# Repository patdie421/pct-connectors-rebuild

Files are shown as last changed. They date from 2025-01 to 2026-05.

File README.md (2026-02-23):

# pct-connectors-rebuild
This repository consolidate all the elements which allow to use an "AE PC Transporter" card in an Apple IIe (my first usage), II+ or IIgs. In particular, It contains elements allowing to recreate the cables and connectors which are generally lost when one of these cards is found.  
Most of the data used to produce the resources of this repository comes from various sources available on the Internet and are referenced in the “useful links” section.  
Colorswitch PCB was created by retro-ingeniring and original card.

<div style="text-align:center;">

figure 1: PC Transporter rev D  
<p>figure 1: PC Transporter rev D (front view)</p>
</div>

## Connector locations  
### PCT Card
<div style="text-align:center;">

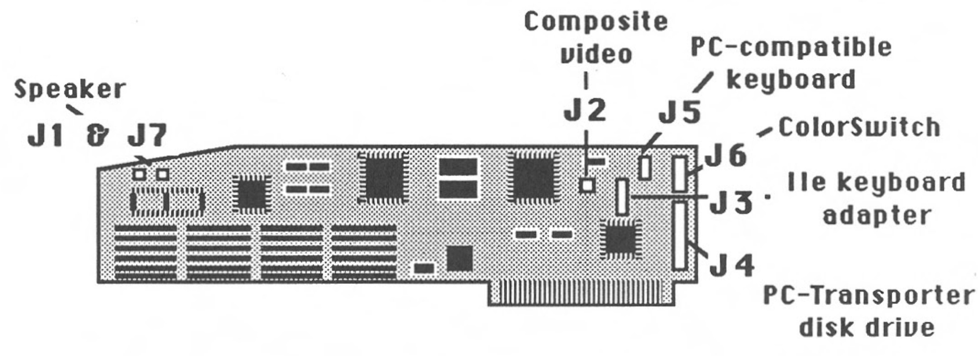
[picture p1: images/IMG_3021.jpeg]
figure 2: PC Transport connector location

<p style="text-align:center;">figure 2: front view card diagram with connector locations</p>
<pre>
J1 - Apple II Speaker motherboard connector (INPUT)
J2 - Composite video (OUTPUT)
J3 - IIe keyboard adapter (INPUT)
J4 - PC Transporter Disk drive (INPUT/OUTPUT)
J5 - PC Compatible keyboard (XT protocol) (INPUT)
J6 - ColorSwitch/CGA (OUTPUT)
J7 - Apple II Speaker (OUTPUT)
</pre>
</div>

### Apple IIe
<div style="text-align:center;">

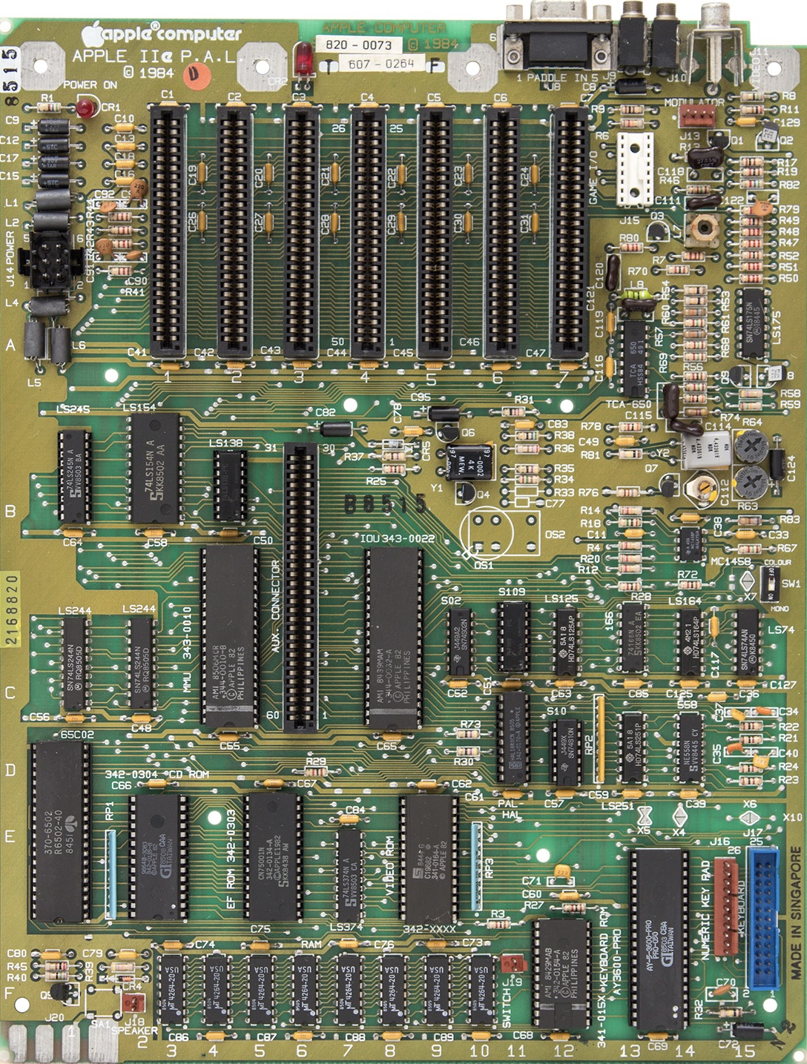
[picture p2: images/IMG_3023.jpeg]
figure 3: Apple IIe PAL motherboard
  
<p>figure 3: Apple IIe PAL motherboard</p>

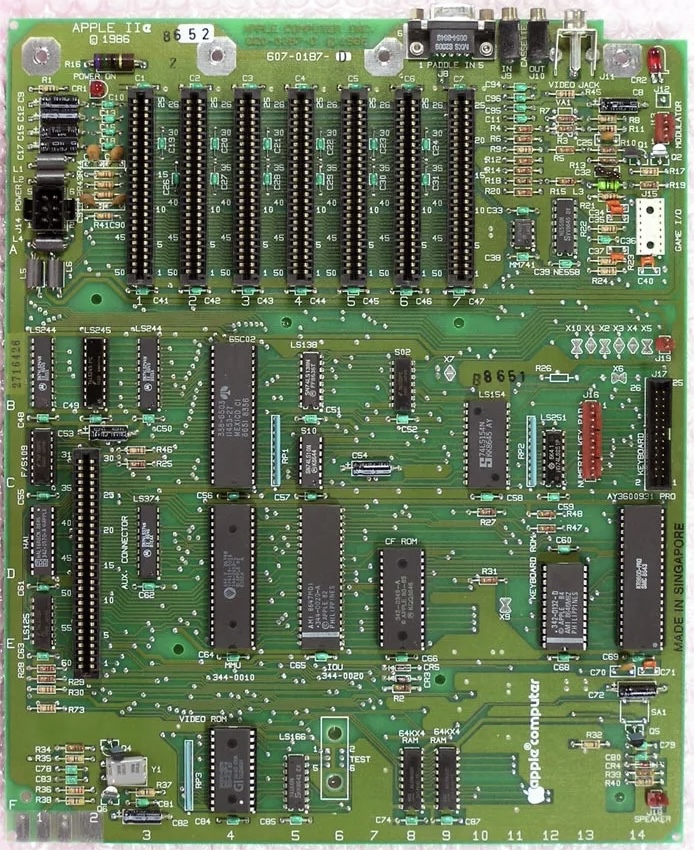
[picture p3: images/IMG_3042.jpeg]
figure 4: Apple IIe (platinum) US motherboard
  
<p>figure 4: Apple IIe (platinum) US motherboard</p>
<pre>
J13 (A14)                  - Composite video (INPUT/OUPUT)
J17 (PAL:E/F15, US:B14)    - IIe keyboard adapter (INPUT)
PAL:J18 (F2), US:J10 (F14) - Apple II Speaker motherboard connector (OUTPUT)
</pre>
Note the different spacing between the keyboard connector (J17) and the numeric keypad connector (J16) of the two card versions.  
</div>

### Original PCT Installation Kit contents
AE solded 2 installation kits to use the card with Apple II+, IIe or Apple IIgs.  

#### IIgs installation kit
- Colorswitch  
- Drive cable  
#### II+/IIe installation kit
- Drive cable  
- Keyboard cable(*)  
- video cable  
- speaker cable  

(*) Apple II+, need an aditional cable for connecting a PC/XT keyboard (kit keyboard cable is inusable for II+) : IBM Keyboard Cable.  
  
#### Digital RGB Adapter (CGA monitor cable)
On II+, IIe and GS you can use a second monitor to display PCT video output. A optional cable was solded by AE.  

## Video Composite output (video cable)
Simple two wires cable. Cheap female/female jumper wire can be used.  
PCT Card outputs an monochrome NTSC composite video signal on J2. PAL motherboards can nevertheless be wired to this Molex connector, but the monitor must be able to switch NTSC and PAL signals (Apple Monitor II is OK for that but the image will "move" a little vertically).  
### PCT Molex connector
<pre>
____
|2||   Video Composite (NTSC)
|1||   GND
----
(PCT connector front view)
</pre>
### Apple II internal Video Connector (J13)
<pre>
===========
| 4 3 2 1 |
-----------
(Apple 2 connector front view)

1  GND
2  Video Composite (NTSC or PAL)
3  -5V
4  +12V
</pre>

### Video Cable
<pre>
Molex  Apple II connector
1  -   1
2  -   2
   -   3
   -   4
</pre>

### status
done, working.

## CGA Video cable (AE: Digital RGB Adapter)
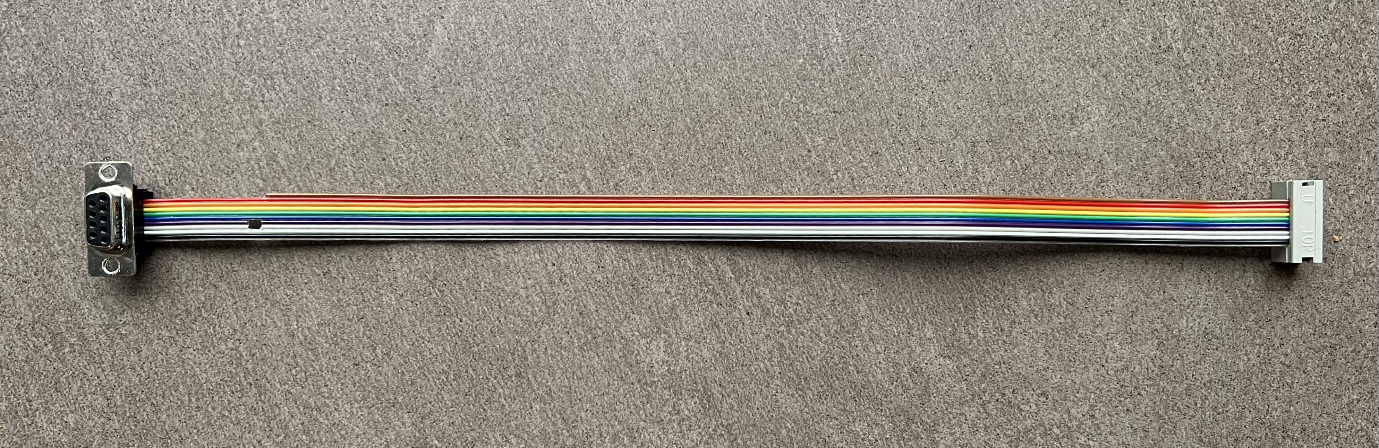
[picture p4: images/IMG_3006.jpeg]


This cable is to use to output video signal directly to a CGA compatible monitor (TTL monitor). Apple II and PCT card can't share easily the same connection for this kind of video connection. Same monitor can display Apple II and PCT signal but for now through two different cables and adaptors (some monitor can automatically switch inputs and "emulate" composite switch or colorswitch behavior)

One side is a DB9 Male connector.
Other one a "10 pins male IDC connector".

Ribbon cable mount connectors are the best way to make this cable. Some parts that could be used :

- IDC : https://fr.farnell.com/en-FR/wurth-elektronik/61201025821/plug-idc-2-54mm-strain-relief/dp/2356318
- DB9 : https://fr.farnell.com/en-FR/multicomp-pro/8ftm09p-30n1-fec/plug-idc-d-threaded-9way/dp/1099306

### 10 pin IDC Male  
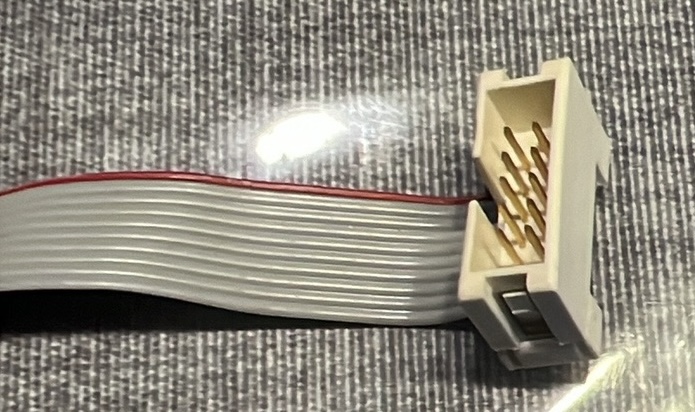
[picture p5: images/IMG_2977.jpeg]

<pre>
(cabel connector front view)  
____________________   
| 2   4   6   8  10|  
| 1   3   5   7   9|  
--------|   |-------  
  |1             |  
  |ribbon  cables|  
  
1 GND
2 Intensity
3 NC for CGA - Source selection for Colorswitch (PCT output signal on CGA/Composite)
4 NC for CGA - CSync for Colorswitch
5 Red
6 HS for CGA - NC for Colorswitch
7 Green
8 VS for CGA - NC for Colorswitch
9 Bleu
10 -
</pre>

### DB9 Female
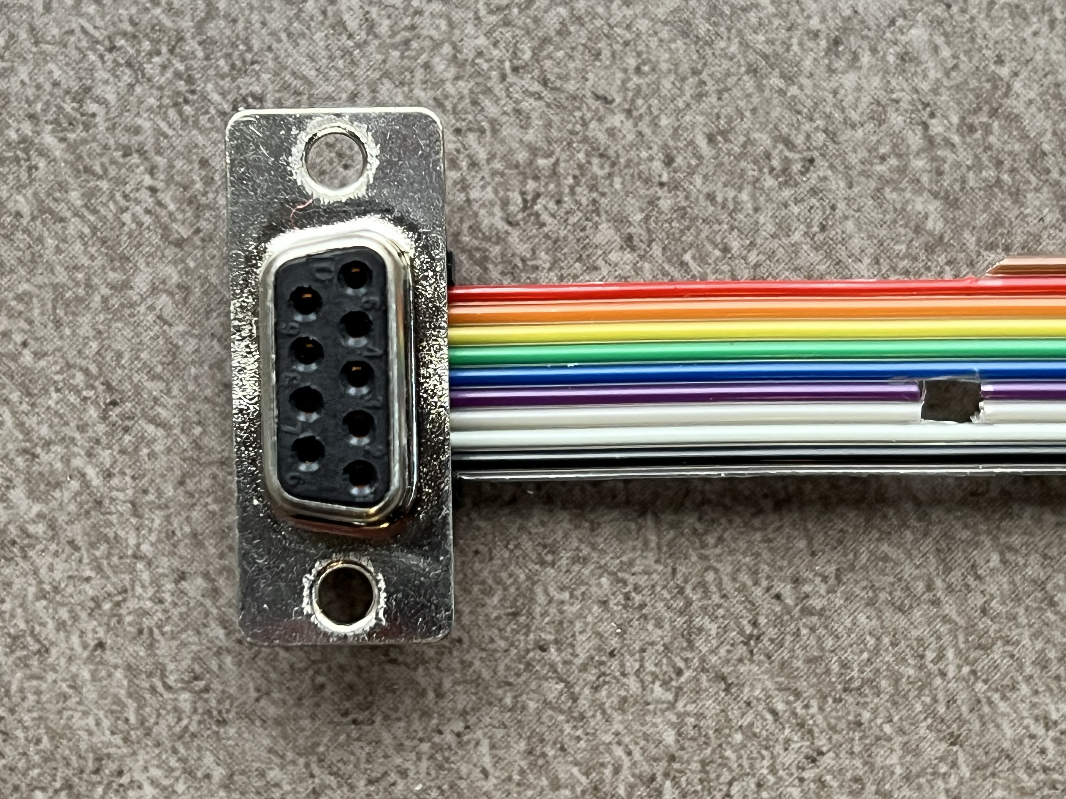
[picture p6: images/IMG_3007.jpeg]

(note the cutout in the ribbon cable)  
  
<pre>
 | ribbon  |
 | cables  |
_|_______ 1|_
\ 5 4 3 2 1 /
 \ 9 8 7 6 /
  ---------
(cable connector front view)

Pin  CGA Function
1    GND
2    GND
3    Red
4    Green
5    Blue
6    Intensity
7    Reserved
8    Horizontal Sync
9    Vertical Sync
</pre>

### Cable
<pre>
IDC      DB9  
  1  --  1  
  2  --  6  
  3  xx  2  
  4  xx  7  
  5  --  3  
  6  --  8  
  7  --  4  
  8  --  9  
  9  --  5  
  10  
</pre>
Do not connect 3 and 4 IDC pins. Cut strands 3 and 4 of the ribbon cable (see photo).  
### usage
The cable connects to J6. There is no key on the male connector, the cable "points" to the right (female connector notch on the right if you look at the board as it is shown in Figure 1). 
### Bonus
You can have cristal clear output on HDMI monitor by using RGBtoHDMI (https://github.com/hoglet67/RGBtoHDMI). The profile to use is : [Commodore/Commodore 128 CGA Brown]  
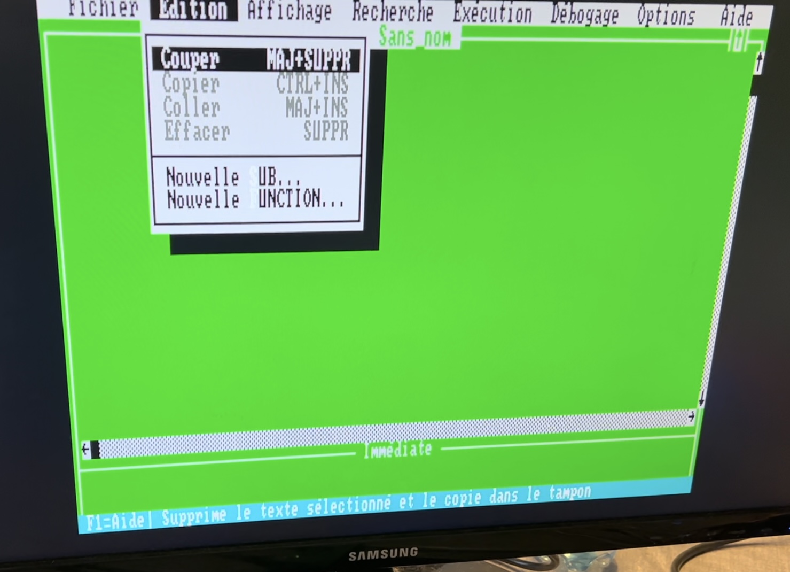
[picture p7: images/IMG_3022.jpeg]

### status
done, working.

## AE ColorSwitch
The ColorSwitch was designed to allow a PCT-equipped Apple IIGS to display CGA on a standard A2M6014 monitor or a compatible RGB monitor (ex: Sony RGB Monitor, cf AE catalog). When the PCT software is running, the display automatically switches Apple screen to CGA screen.  
This card can also be used with an Apple 2e using an RGB color card (Chat Mauve Féline in my case).  
<div>
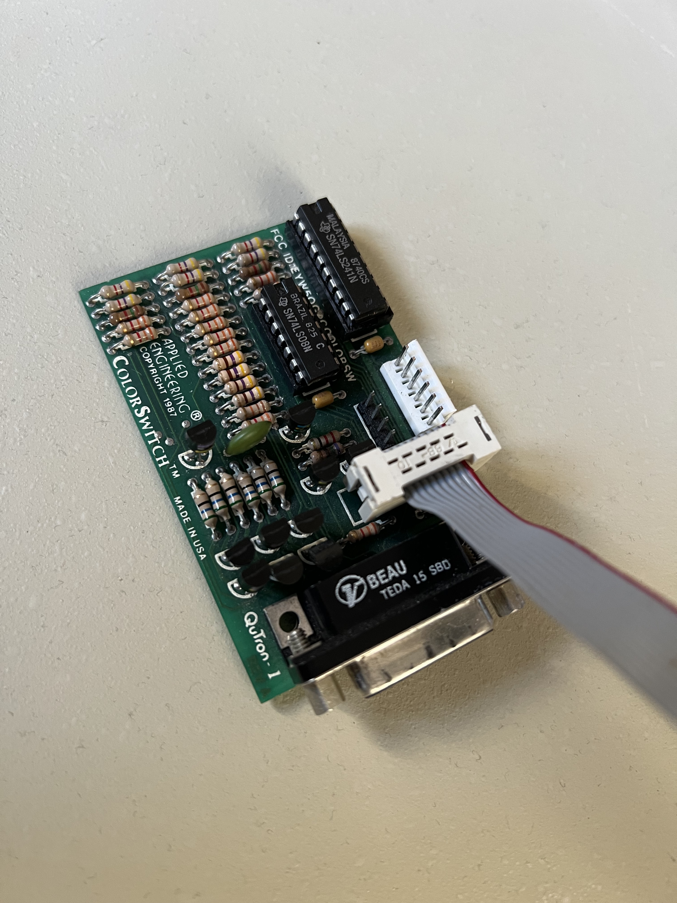
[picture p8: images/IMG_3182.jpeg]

</div>
<div>
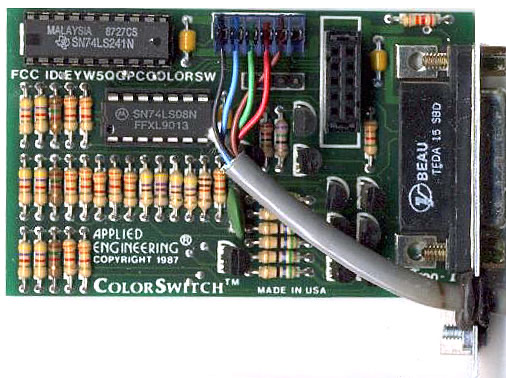
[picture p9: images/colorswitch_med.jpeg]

</div>

### PCB
A design is available in "hardware" folder (v0.0 is buggy, v0.2 should work).  
This design differs from the original device. The implementation density of components is reduced (easier to solder) and the faulty and unused/useless* composite video signal circuit has been removed.  
(*) would have been useful with a specific monitor able to display RGB and composite. Could be add in a futur version.   
<div>
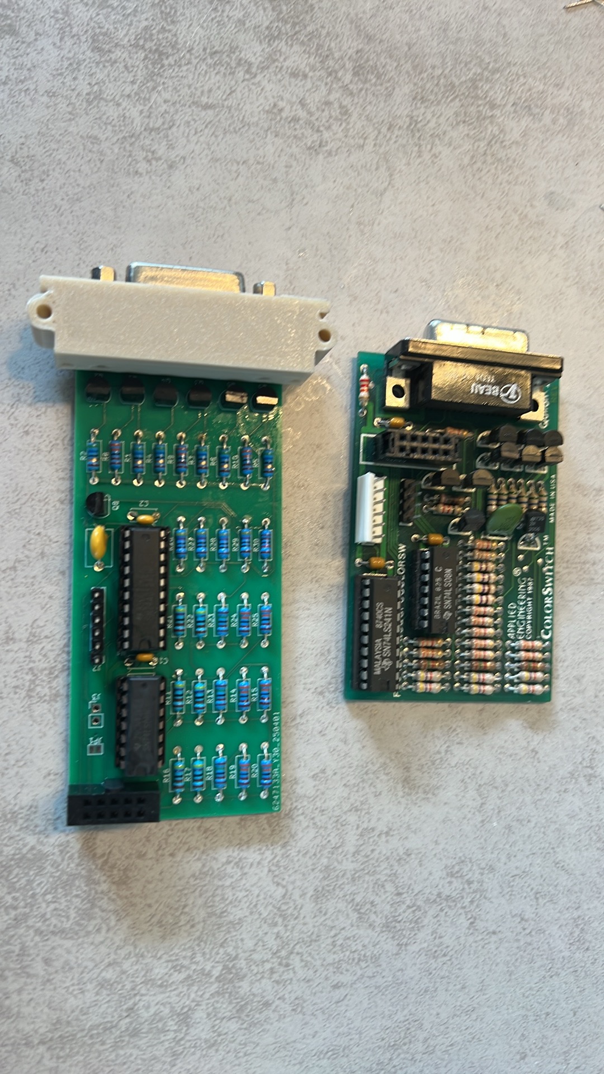
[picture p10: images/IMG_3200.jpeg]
   
   Rebuilt ColorSwitch (v0.0) with DB25 mounting bracket compared to original 
</div>

#### ColorSwitch DB15 female connector
<pre>
1 : RED GND
2 : RED
3 : CSYNC
4 : -
5 : GREEN
6 : GREEN GND
7 : -
8 : -
9 : BLUE
10 : -
11 : -
12 : -
13 : BLUE GND
14 : -
15 : -
</pre>

### ColorSwitch IDC6 connector
<pre>
1 : CSYNC
2 : (composite)
3 : GREEN
4 : RED
5 : BLUE
6 : GND
</pre>

### PCT to Colorswitch cable
flat cable with 2 idc10 male connector.  
<div>
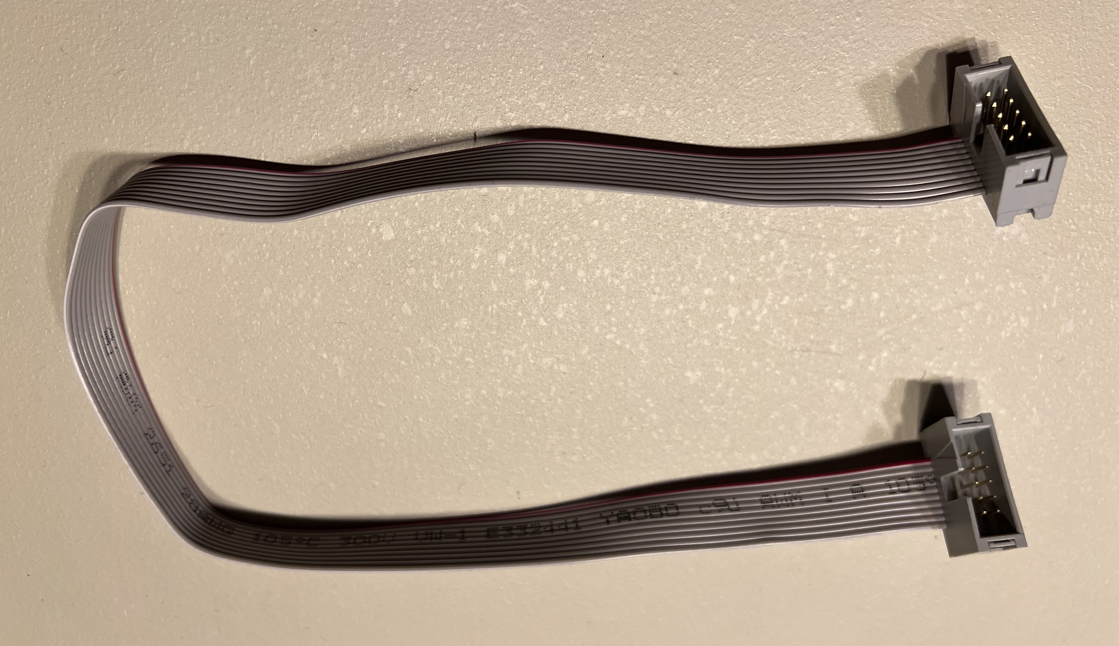
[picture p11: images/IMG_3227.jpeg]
   
</div>
<pre>
IDC10  IDC10  
   1 -- 1
   2 -- 2
   3 -- 3
   4 -- 4
   5 -- 5
   6 -- 6
   7 -- 7
   8 -- 8
   9 -- 9
  10 -- 10
</pre>
flat cable with 2 idc10 male and 1 db9 male connector. To use for double monitor connection.  
(photo)
<pre>
IDC10  IDC10   DB9  
  1  --  1  --  1
  2  --  2  --  6
  3  --  3  xx  2
  4  --  4  xx  7
  5  --  5  --  3
  6  --  6  --  8
  7  --  7  --  4
  8  --  8  --  9
  9  --  9  --  5
  10 -- 10
</pre>

### db15 to Colorswitch (IDC6) cable (for Apple IIGS)
<pre>
DB15 (male)   IDC-6
1 : GND         6
2 : RED         4
3 : CSYNC       1
4 : -
5 : GREEN       5
6 : GND         6
7 : -
8 : -
9 : BLUE        9
10 : -
11 : -
12 : -
13 : GND        6
14 : -
15 : -
</pre>

### Chat Mauve to Colorswitch cable
Several connection are possible. You can use internal (on card) or external connector (throug db connectors).

#### Chat Mauve on card IDC8 connector
<pre>
(card connector front view)  
  =================  
  |1 2 3 4 5 6 7 8|  
  -----------------  
1 - RGB/Composite commutation
2 - Audio out
3 - CSYNC (75 Ohms, 0.5V)
4 - RED (75 Ohms, 0 to 0.7V)
5 - GREEN (75 Ohms, 0 to 0.7V)
6 - BLUE (75 Ohms, 0 to 0.7V)
7 - GND
8 - 12V
</pre>
#### BONUS 1 : Chat Mauve Féline on card IDC10 connector (connector need to be soldered)
<pre>
  (card connector front view)
  ---------------
  |2  4  6  8 10|
  |1  3  5  7  9|
  ---------------  
 1 - NC
 2 - 12v
 3 - GND
 4 - Blue
 5 - Green
 6 - Red
 7 - CSync
 8 - Audio
 9 - NC
10 - NC
</pre>
#### Chat Mauve DB9 female connector
<pre>
 (cable connector front view)
_____________  
\ 5 4 3 2 1 /  
 \ 9 8 7 6 /  
  ---------  
1 : NC  
2 : GND  
3 : GREEN (75 Ohms, 0 to 0.7V)  
4 : CSYNC (negative, 75 Ohms, 0.5V)  
5 : RGB/Composite commutation  
6 : 12V
7 : BLUE (75 Ohms, 0 to 0.7V)  
8 : RED (75 Ohms, 0 to 0.7V)  
9 : Audio out
</pre>

#### BONUS 2 : Chat Mauve to A2M6014 compatible monitor
<pre>
DB9    DB15      IDC8    DB15     IDC10*  DB15
  1 --              1 --             1  --  
  2 -- 1,6,13       2 --             2  --  
  3 -- 5            3 -- 3           3  -- 1,6,13
  4 -- 3            4 -- 2           4  -- 9
  5 --              5 -- 5           5  -- 5
  6 --              6 -- 9           6  -- 2 
  7 -- 9            7 -- 1,6,13      7  -- 3
  8 -- 2            8 --             8  --  
  9 --                               9  --  
                                    10  --  
</pre>

#### BONUS 3 : Colorswitch (or 2gs) to scart cable
##### Scart pinout (wire side view)
<pre>
  _____________________________
 |1  3  5  7  9 11 13 15 17 19 |
 | 2  4  6  8  10 12 14 16 18 20\
  -------------------------------
5  - RGB Ground Blue
7  - RGB Blue In
8  - Switching
9  - RGB Ground Green
11 - RGB Green In
13 - RGB Ground Red
15 - RGB Red In 
16 - Blanking Signal  
17 - Ground Composite Video
18 - Ground Blanking Signal
20 - Composite Video In (CSYNC)
(Only needed pins are listed)
</pre>

##### cable
<pre>
   DB15 (male)     scart (male)
    1,6,13   ---   5,9,13,17,18
      2      ---   15
      3      -*-   20
      4
      5      ---   11
      7
      8      -o-   8
      9      ---   7
     10
     11
     12
     14
     15
(-*-) : direct wire or 190 Ohms resistor
(-o-) optional : to use the cable with the 2gs db15 connector add a 390 Ohms resistor
</pre>

#### BONUS 4 : Chat Mauve TTL / Taxan Model 410-80 connector to rgbtohdmi
It is now possible to use TTL Taxan video card with Colorswitch by using a TTL xRGB to RGB convertor. You can found it a this location: https://github.com/patdie421/xrgb2rgb  

### Status
v0.0 : partially working, color inversion but pcb OK  
v0.2 : done working.  
v0.3 : new smaller PCB - done, working but component mounting issue.  
v0.4 : component position adjustment and sub-d 15 alternative part mount. Tested, working.  

## Storage connector (AE: drive cable)  
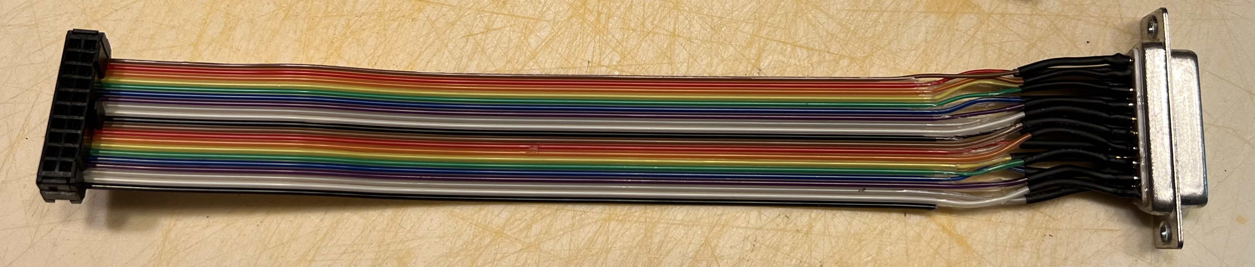
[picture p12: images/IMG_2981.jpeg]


### 20 pin IDC Female  
<pre>
_________________________________________   
| 20  18  16  14  12  10  8   6   4   2 |  
| 19  17  15  13  11   9  7   5   3   1 |  
------------------|   |------------------  
 |                                    1|  
 |           ribbon cables             | 
     (cable connector front view)  
</pre>
### DB19 Female
<pre>
  |                              |
 _|_____________________________1|_
 \  10  9  8  7  6  5  4  3  2  1 /
  \  19 18 17 16 15 14 13 12 11  / 
   ------------------------------  
    (cabpe connector front view)

Pin Function apple pinout
1   GND      GND
2   GND      GND
3            GND
4            GND (IIgs: /3.5DISK bidirectional)
5            -12V
6   5V       +5V
7   12V      +12V
8   12V      +12V
9            /ENABLE2 (IIc /EXTINT)
10           WPROD (Macintosh: PWM)
11           PHASE0
12           PHASE1
13           PHASE2 
14           PHASE3
15           /WREQ
16           (Machintosh: SELECT, IIe/II+: +5V, IIc: N.C., IIgs: SELECT bidirectional)
17           /ENABLE (II+/IIe/IIgs: /ENABLE1)
18           RD
19           WR
</pre>

### Cable
<pre>
IDC    DB9  
1  --  1  
2  -- 11  
3      2  
4     12  
5  --  3  
6  -- 13  
7  --  4  
8  -- 14  
9  --  5  
10 -- 15
11 --  6
12 -- 16
13 --  7
14 -- 17
15 --  8
16 -- 18
17 --  9
18 -- 19
19 -- 10
20
</pre>
### usage
The IDC connector is keyed (the cable is oriented towards the inside of the apple II). Connect 800ko 3.5" Apple floppy drive (/!\ do not connect 3.5" unidisk) or AE Transdrive to DB19 connector. Drive can be daisy chained check documentation.

### status
done, working.

## Apple 2e keyboard adapter (AE: keyboard cable)
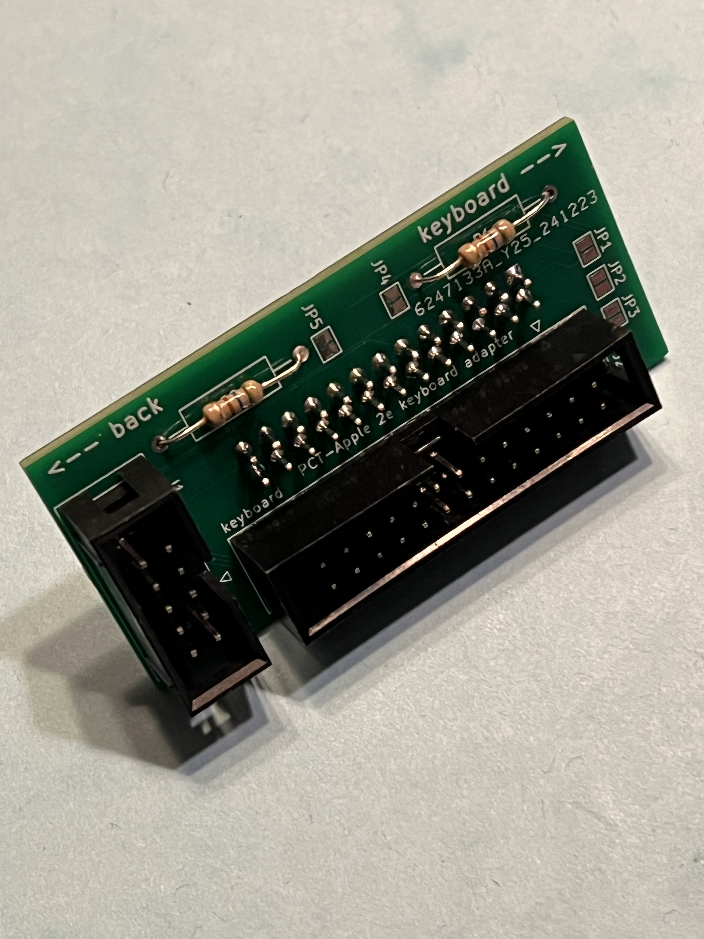
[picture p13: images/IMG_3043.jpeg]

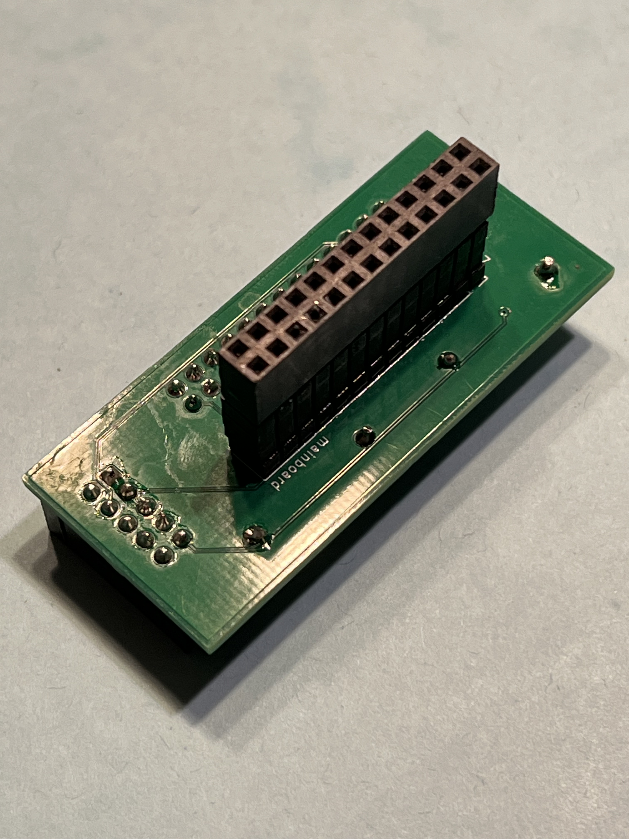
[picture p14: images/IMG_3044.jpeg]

The keyboard adapter is a small PCB and a ribbon cable supplied as an option with the PCT card. This adapter is placed between the Apple motherboard and the keyboard and provides status of "dead keyboard keys" (control, shift, Apple open/close and capslock) to the PCT card. The other signals are only pass-throughs from the keyboard to the motherboard of the Apple 2e.

### connections
Connections are described in this [schema](hardware/a2keyboardToPCT/a2keyboardToPCT.pdf)

### PCB
Based on the connections schema, the PCB can be found in this repository:
[KiCad project and gerber files](hardware/a2keyboardToPCT/V0.0)  
The original version of the connector was designed for a US motherboard. It can be installed on a PAL computer but the connector for the numeric keypad may conflict with the keyboard adapter.  
This PCB is roughly the same size and layout as the original one and therefore may have the same issue. It is best to use elevated female IDC connector if used with PAL Apple IIe (for example https://fr.farnell.com/en-FR/samtec/esq-113-44-t-d/connect-femelle-26-voies-2-rangs/dp/2779437).
### status
done, working.

## PC Compatible keyboard (AE: IBM Keyboard Cable)
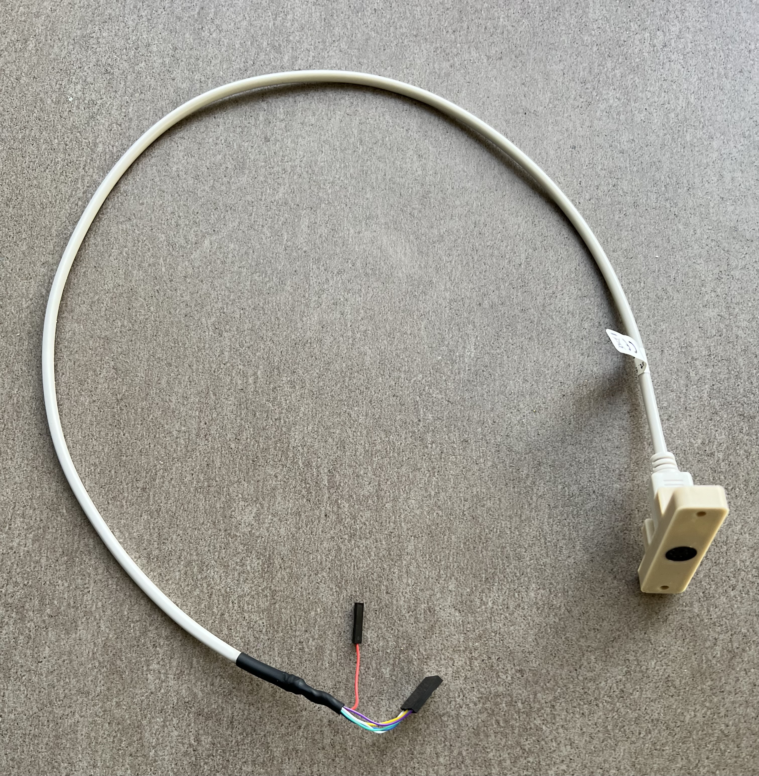
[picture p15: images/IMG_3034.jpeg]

This cable is based on a "PS2 extension cable for keyboard and mouse" (like https://amzn.eu/d/a3pizTv) cut approximately 50 cm after the female connector. An 5 pins JST connector (molex connector alternative) is connected to the cables. The female connector is glued into a 3D printed mounting enclosure that can be attached to one of the db9 or db25 (2 versions available) cutouts on the back of the Apple IIe. This first version of the connector need an AT (PS/2) keyboard able to use the XT protocol. Not all AT keyboards are capable to use this protocol, rare older AT keyboards have automatic or manual switching capabilities from AT to XT protocol.  
<p>
/!\ An active protocol translator for using a ps/2 keyboard as an XT keyboard can be found here: https://github.com/asig/ps2-to-xt-adapter/tree/master. Work is done to integrate it on a small PCB directly pluggable onto the PCT card.
</p>

### Molex connector
<pre>
____
|5||   +5V
|4||   GND
|3||
|2||   Data
|1||   Clock
----
(cable connector frond view)
</pre>

### PS/2 Connector
<pre>
    6  N  5
   4       3
     2   1
(socket/female front view)

Pin   Function
 1    Data
 2    NC
 3    GND
 4    +5V
 5    Clock
 6    NC
</pre>
### PS/2 Cable
<pre>
Molex  PS/2
 1  -  5
 2  -  1
(3  -  2) - 2 unused pins, connection not needed
 4  -  3
 5  -  4
       6
</pre>
### status
Cable: done, working  
XT/AT converter: done, working  
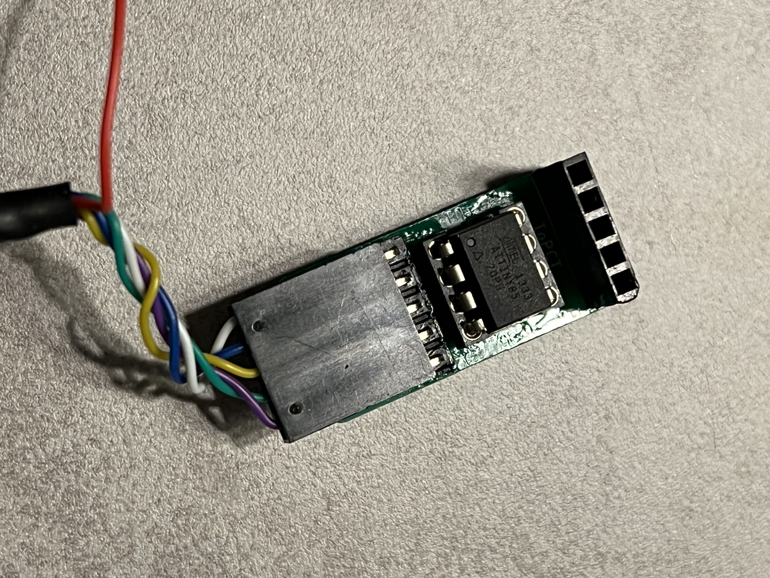
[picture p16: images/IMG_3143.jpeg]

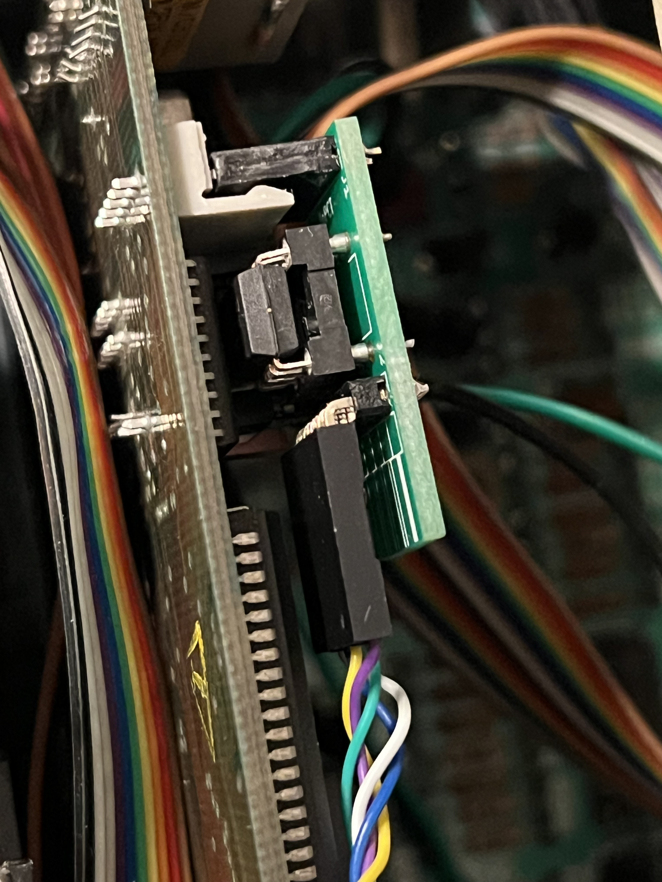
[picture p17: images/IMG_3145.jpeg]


## Sound Connector
One or two Simple two wires (dupont) cable. Cheap female/female jumper wire can be used to connect motherboard J18 to PCT J1. If the speaker cable is long enough it can be connected directly to the J7 connector of the PCT card. If not, a cheap female/male jumper wire can be used.

### PCT Molex connector (J1 / J7)
<pre>
____
|2||   Sound signal
|1||   +5V
----
(PCT connector front view)
</pre>

### Apple II speaker
<pre>
____
|2||   Sound signal
|1||   +5V
----
(Apple II connector front view)
</pre>

## GOTEK + flashfloppy as secondary drive in single TransDrive
3D printed enclosure, configuration and cables.

### Enclosure
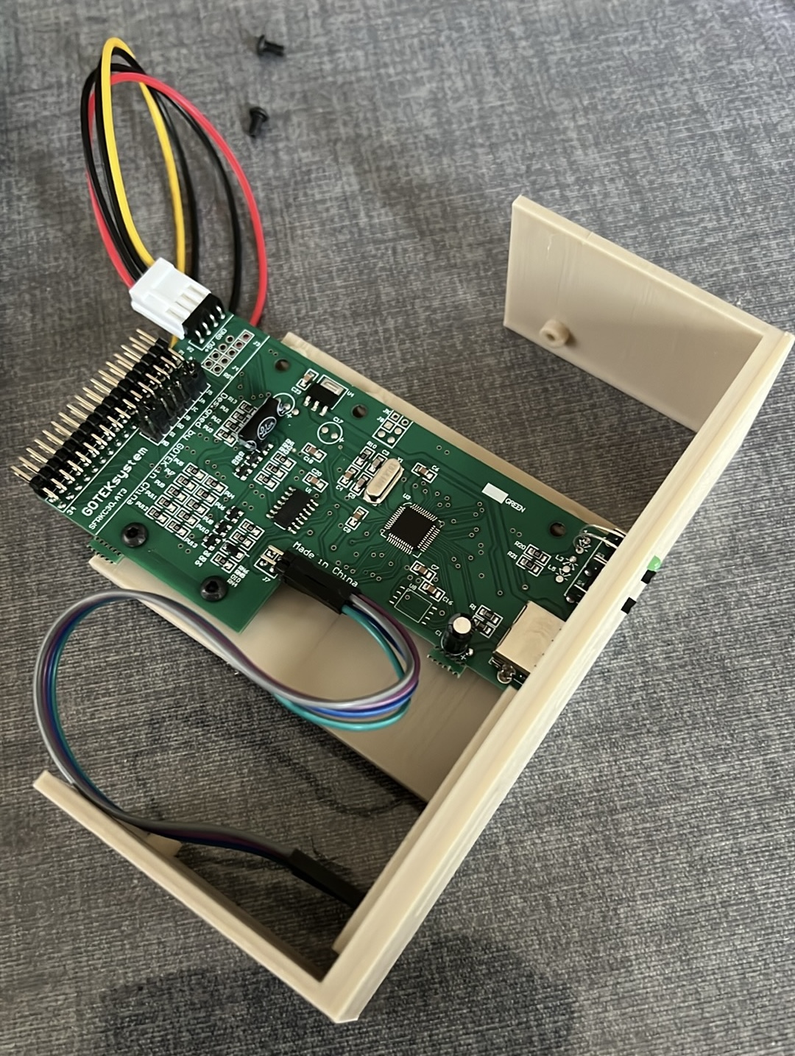
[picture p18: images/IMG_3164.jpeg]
  
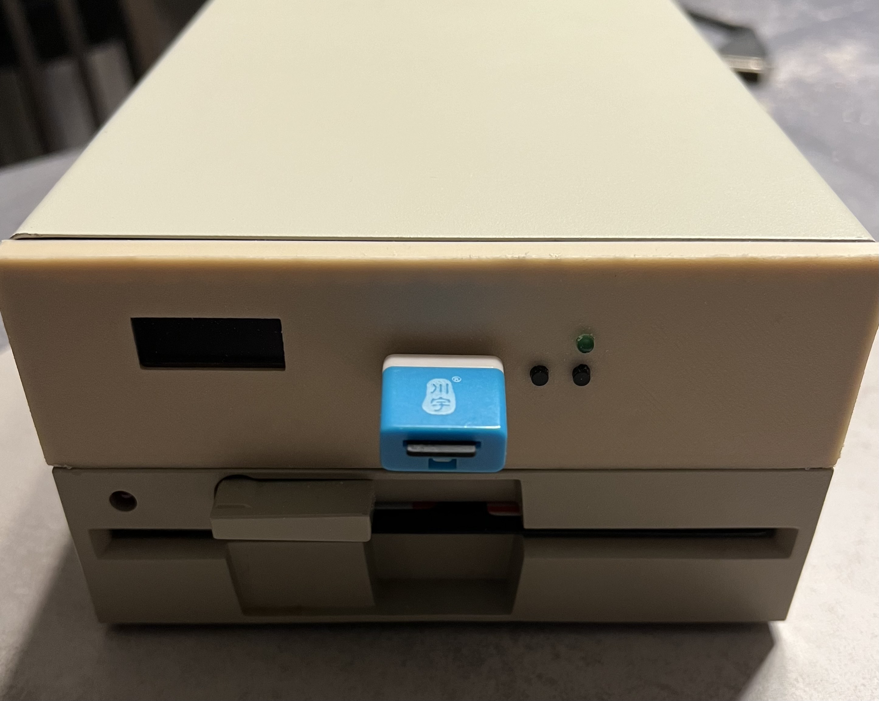
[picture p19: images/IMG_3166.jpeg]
  

[Gotek enclosure with OLED sceen](hardware/transdriveGotek/v0.0)

### Configuration
https://github.com/keirf/flashfloppy  

### Cables
The cable provided with the TransDrive isn't long enough to connect the Gotek. You need to find (or build) an other cable.  
(to do)

## useful links
PCT documentations and software  
https://ae.applearchives.com/all_apple_iis/pc_transporter/  

French PCT documentation  
http://www.apple-iigs.info/doc/fichiers/Brejoux_PC_Transporter%202.pdf  

Various PCT Pinouts and adaptaters (but not exhaustive)  
https://www.applefritter.com/appleii-box/harrowalsh.de/APPLEBOX/APPLE2/Manuals/AE%20PC%20Transporter%20ComponentsPinouts.pdf  

Pinouts, adapters and other resources  
https://osites.tripod.com/transport.html  

Schematics and PCB for 5.25" and 3.5" PC floppy drive adapter rebuild  
https://www.applefritter.com/appleii-box/H070_AppleIITransDriveAdaptor.htm  

Pinouts of various Apple II, Apple IIe, Apple IIc, Apple IIgs and Apple Printers connectors  
https://mirrors.apple2.org.za/ftp.apple.asimov.net/documentation/hardware/misc/Apple%20II%20Family%20Pinouts.pdf  

RGB TTL to RGB Analogic  
https://downloads.reactivemicro.com/Apple%20II%20Items/Hardware/Apple_II_AppleColor_TTI_RGB/TheMarcorlandiModification_TTLRGB.pdf  

Apple 2GS to SCART (for ColorSwitch to SCART)  
https://www.brutaldeluxe.fr/documentation/cortland/v3_03_Schematics.pdf  

For photos  
https://www.applefritter.com/content/applied-engineering-pc-transporter-and-drives

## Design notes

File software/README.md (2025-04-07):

To use the PCT in good conditions it is preferable to have a ProDos hard drive. This disk can be a real disk connected to the II+/IIe/IIgs by one or other of the original solutions (SCSI card + HDD, Apple Profile, etc.) or a modern solution (SmartPort Emulator). However, not all solutions are compatible (I have already identified a solution that did not work), do your own tests if necessary.  

minimum storage device requirements to start MS-DOS with PCT :
- 1x 140ko floppy drive (real or emulated)  
(this solution is to be tested)  

minimal usable configuration :
- 1x ProDOS bootable floppy drive (5.25" floppy drive is OK)
- 1x Apple 3.5" floppy drive (/!\ not Unidisk 3.5") plugged to DB19 connector at the back of the PCT

Optimal solution :
- 1x ProDOS bootable floppy drive (5.25" floppy drive is OK)
- 1x Apple 3.5" floppy drive (/!\ not Unidisk 3.5") plugged to DB19 connector at the back of the PCT
- 1x Real or emulated hard drive (>10 Go)

Top solution :
- 1x ProDOS bootable floppy drive (5.25" floppy drive is OK)
- 1x Transdrive (1x or 2x 5.25") plugged to DB19 connector at the back of the PCT
- 1x Apple 3.5" floppy drive plugged to DB19 connector at the back of the Transdrive
- 1x real or emulated hard drive (On or two 32 Go partitions)

# Prebuild disk images

**pc_transporter_13_disks.zip** (1.32) and **pc_transporter_20_disk.zip** (2.04): original software for PCT Card  

**AEPCHD.2img**: hard drive disk image with PCT software (no dos hdd)  

**PCT204-msdos401us-v0.disk**: Apple II hard drive disk image with PCT 2.04 configured with:  
- A: apple drive 3.5",  
- C: 20MB Hard drive with MS-DOS 4.01 US (full install), no other software installed
- D: PCT Drivers and tools  
(tested with Apple SCSI Card + BlueScsi and LIRON Card + floppy Emu)

**VOL01_HDD01.po**: hard drive disk image with PCT 2.04 configured with:  
- A: transdrive 5.25" (drive 1),
- B: apple drive 3.5" (drive 1),
- C: 30MB Hard drive with MS-DOS 4.01 US (full install) with software :
  - Turbo C++ 1.0
  - Turbo Pascal 5.5
  - Wordstar 4
  - Norton 5
- D: PCT Drivers and tools  
(tested with DAN ][ - [https://github.com/profdc9/Apple2Card](https://github.com/thorstenBr/Apple2Card))  

PCT software does not seem to work with A2Pico + a2retronet (https://github.com/oliverschmidt/a2retronet)

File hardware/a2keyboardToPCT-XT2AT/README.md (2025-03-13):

Add-on for modern AT / PS/2 keyboard.  
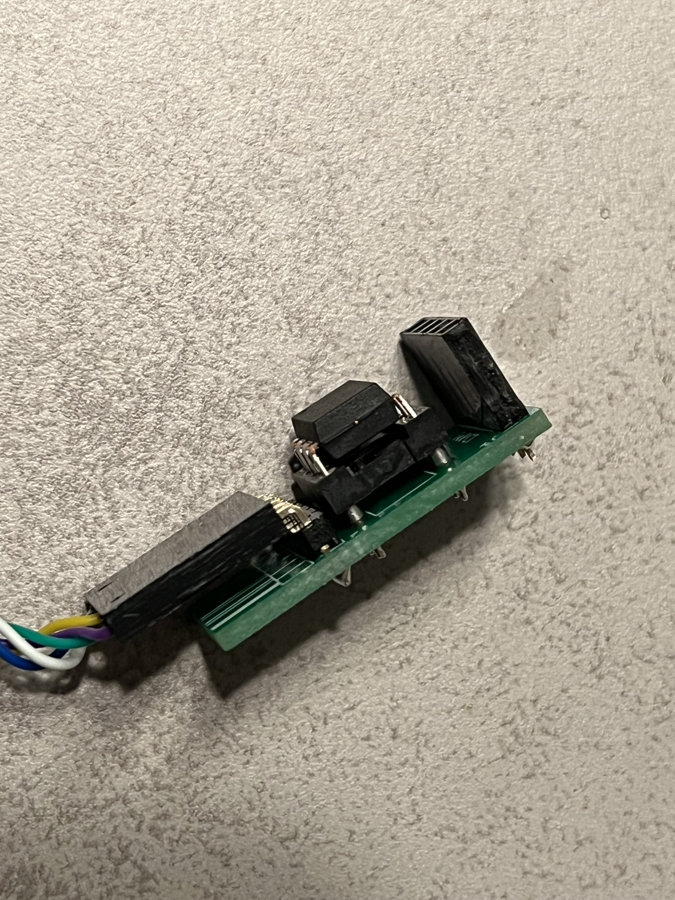
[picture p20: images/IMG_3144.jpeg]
  
PCB tested, working !  
Some key swap issues with some kind of keyboard (Attiny software to update ?).

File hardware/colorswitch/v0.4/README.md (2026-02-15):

Update to reduce production price
- Two kinds of Sub-D connector mounting system (J4 or J5)  
- standard 10 pin connector can accept 14 pin connector (J1)  

Silkscreen layer have more informations

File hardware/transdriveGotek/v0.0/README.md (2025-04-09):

<div>
  
</div>
<div>
Gotek (with oled display) mounting kit for transdrive 5.25 bay.  
</div>

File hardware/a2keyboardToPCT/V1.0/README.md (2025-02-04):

Smaller footprint than v0. Not tested yet.

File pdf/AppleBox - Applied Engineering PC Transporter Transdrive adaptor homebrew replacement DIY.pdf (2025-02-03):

# Homebrew replacement Floppydiskadaptor for

MS-DOS drives on the AE PC Transporter card (https://www.applefritter.com/appleii-box/065_AEpctransporterFloppyAdaptor.htm)

Page No.:H070

In 2012 i purchased a PC-Transportervard from Applied Engineering. Unfortunately i had no chance to also buy an so called "Transdrive" from Applied Engineering too - allthough such a drive is required to operate the PC-Transporter card. Without such drive its not really possible to activate the PC-Transporter card, because you cant boot MS-DOS from an Apple diskdrive.

So after the card was tested by only using the card internal function menu - the further usage was set apart waiting for either the chance to get in touch with an original "Transdrive" from Applied Engineering or if that requires too much time by making a substitute adaptor. In the meantime i decided to make a homebrew Adaptor as substiture for the use with a regular PC-Floppy drive replacing the "Transdrive". I remembered that in the mid 80s in the German User magazine from AUGE ( Apple User Group Europe ) a page had been published with a description how to connect a MS-DOS floppydrive to the PC-Transporter. In the mid of 2013 i started scanning the USER MAGAZIN from AUGE to get them in digital format ready for my archive. When i scanned the Issue that contained that mentioned page - i splitted the copy of that page apart and saved a copy to my "pending projects" directory.

Here is a copy of that page:

Now in september i picked up that page and started with the task. First of all i decided that i didnt want to wire up that with simple experimantal board, but instead i wanted to use a real PCB instead. At the other hand after i had transferred the plan into my PCB- design software i had to realize that eith normal use the PCB would require at least a double sided PCB - but i wanted to avoir at the one hand the delay of 14 days caused by sending the gerber files to a PCB-manufacturer and waiting for shipment of the finished PCBs and at the other hand such a task would have cost at least 100 to 150 Euro - even for such a tiny board.

Then while changing the design - to reduce the wirebridges requested - if i would reduce the PCB to a single sided layer - i also thought about the possinility of making two boards - one for pulling "straight through" a 20 pin flatribbon cable from PS-Transporter Card to the adaptor - or as alternate version - another PCB with a fixed 19-pin DB19 shell connector which would permit to use a "straight through" 19-wire cable with DB-19 connector at both sides prepared for mounting in fixed position in a case with 2 MS-DOS drives.

In the population picture above the requsted wirebridges are drawn in red color.

due to european laws and german court decision:
I hereby declare no responsibility to any "deep links" resulting from the links in this page. I have no influence to the pages linked hereby in this page and the contents in those pages. I therefor cant take any kind of responsibility to contents in the pages, where these links direct the readers browser to nor to the
contents resulting from following up links from those pages. The reference to contents by this links is dependent ro the status of the date when the links have
been set ( April 2013 ) and it might occur that references and contents may change by the fact that domains may have been discontinued from their former owners. In such cases i cant take any kind of responsibility to the changed contents. this is specialy valid to banners, advertisements or merchandising links in the targeted pages.

# HowtoconnectaStandard-MSDOS-Drive(360k-5.25"or720k-3.5")toan

# AEPC-TransporterCard. TOONOREUNH

13
14

GND
GND
コ | 28(34)
5V8(34) 3/07
2/13830(34) 5/07

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
# Picture2 Sangestionettore34-pin

19

### Picture1

←-

## GND

14 | 5v

### Picture3

# TheFenginingconnectionsat

8a

# The remaining connections ac

# (TranslatedfromapublicationintheGermanAUGE-User-Magazine7/88)

# Youneedthefollowingparts:

# 1or2Shugart-Bus-Connectors(female,34pins)

1AppleDisk-Port-Connector(male,19pins) about50cmofcable(whichallowsyoutoconnect19pins) about50cmofcableforthe34-pin-Shugart-connectors

## 1IC7407N 1IC74LS138/1

# 2capacitorsofeach100nF

# 4resistorsofeach2.7k0hm 2sockets(better)fortheICs

## 1littletestingboard

# Thebestwaytobuildthisadapter(interface?)istodoitwithalittleboard(about3by3

# inches).Firstsolderthetwosockets,thensoldereachofthedescribedconnections-oneby

one.

# ThesecondMSDOS-Driveisconnectedparalleltothefirst-adressingisdonebysettingthe

drive-select-jumpertoD1,ifthefirstisDO(orD2,ifthefirstwasD1).

## Powerz CONN01X04 TransdriveAdaptor

DB19

74LS138

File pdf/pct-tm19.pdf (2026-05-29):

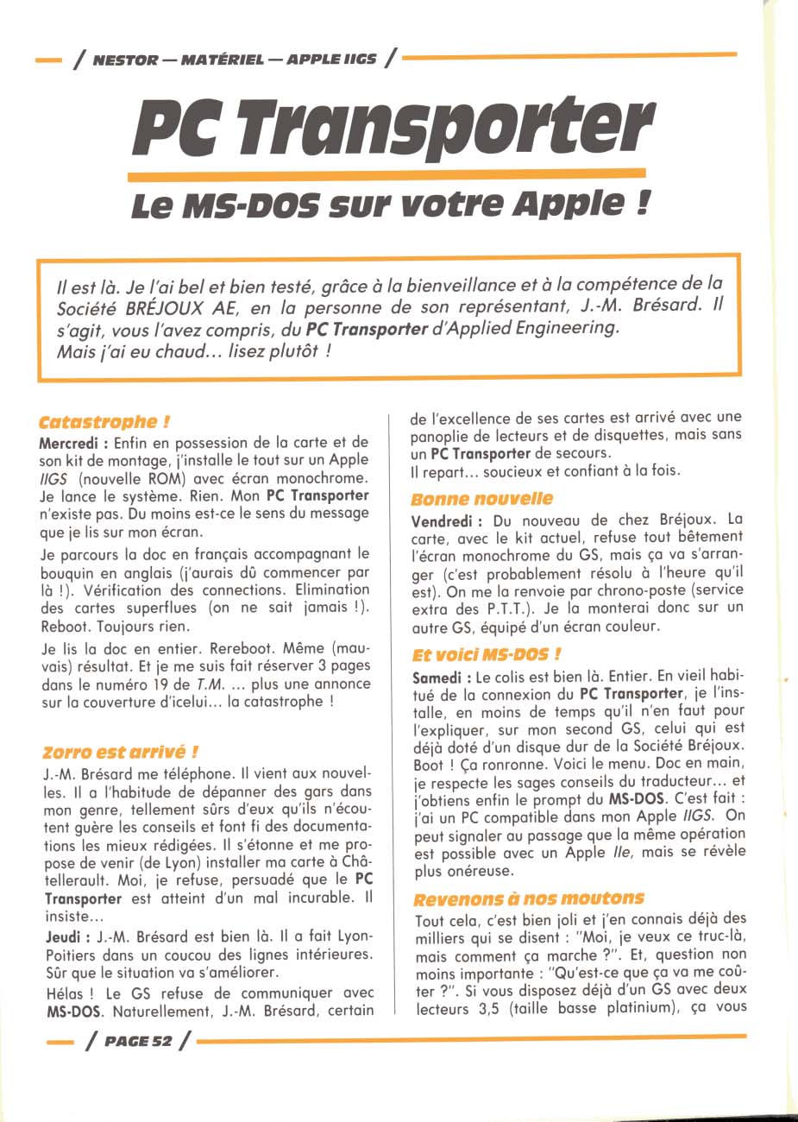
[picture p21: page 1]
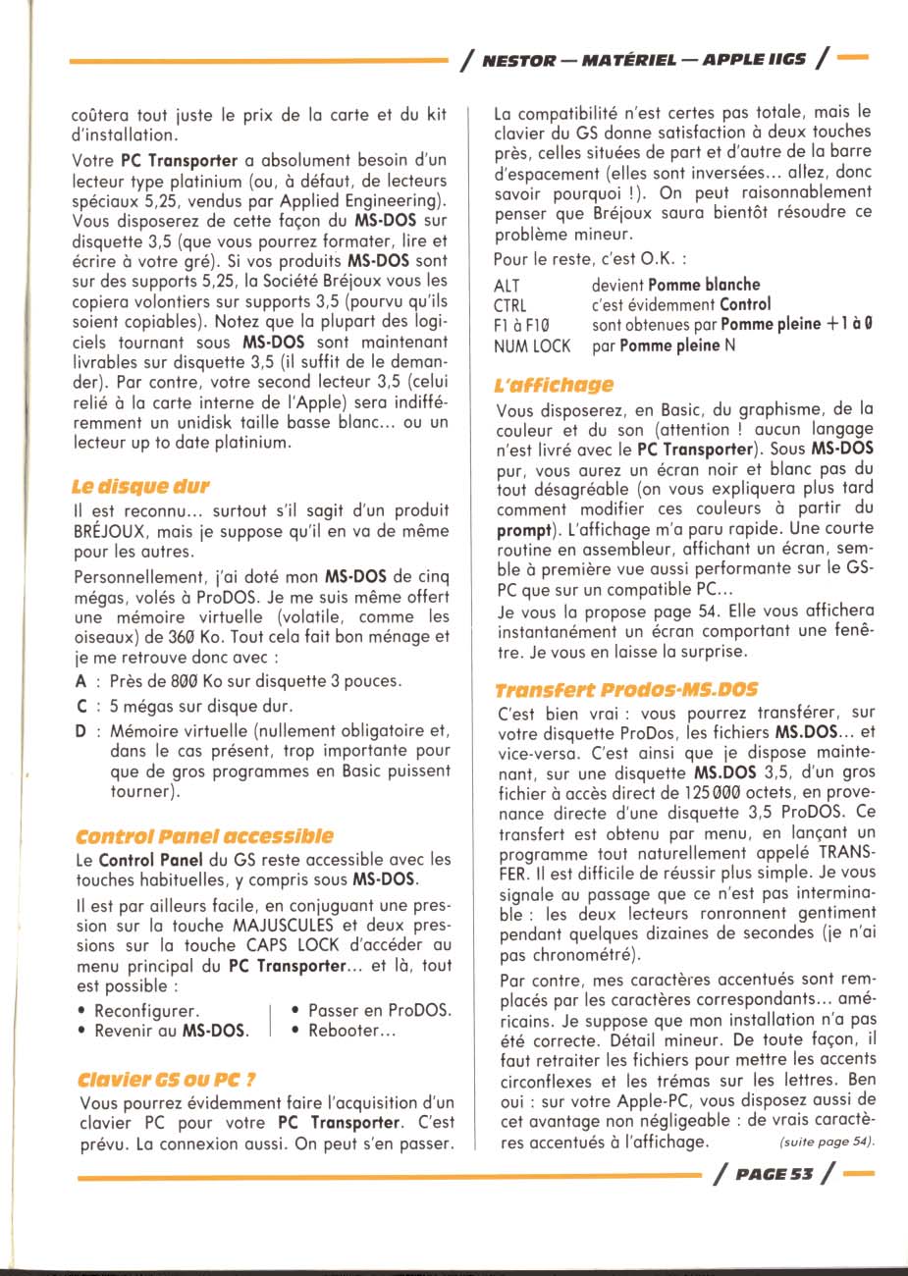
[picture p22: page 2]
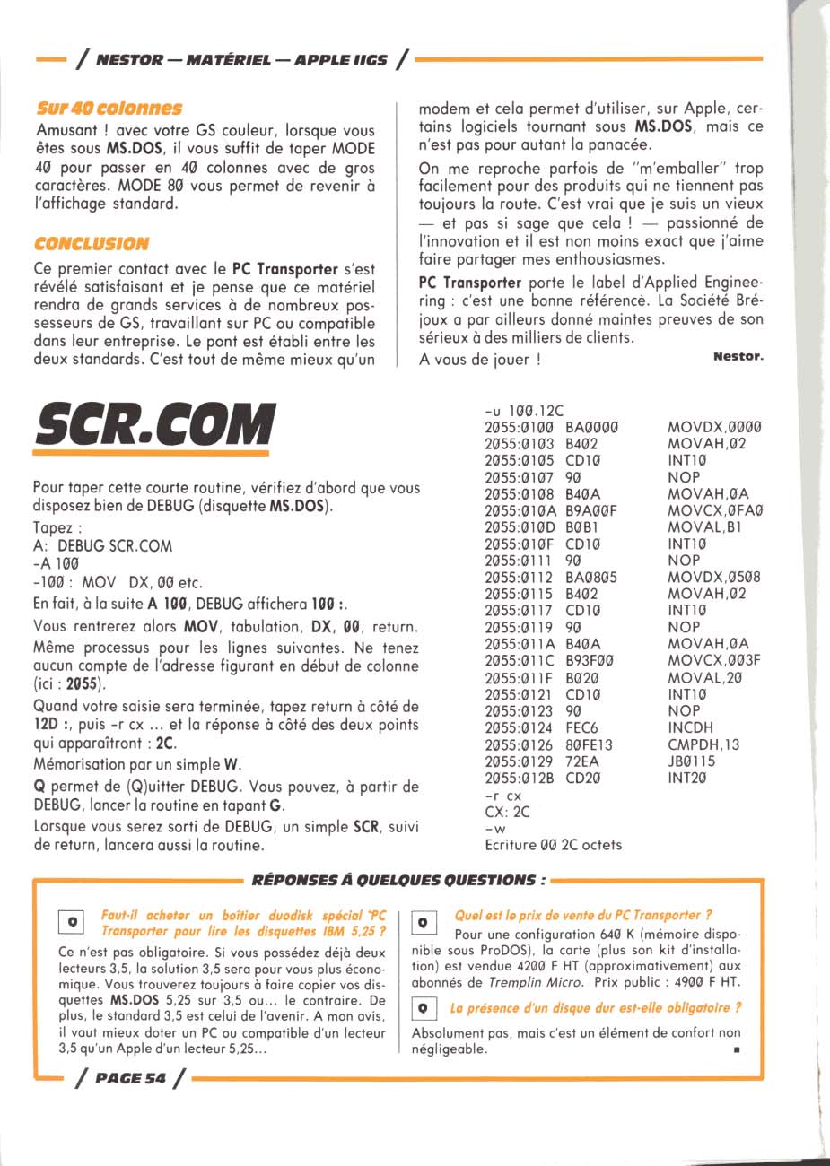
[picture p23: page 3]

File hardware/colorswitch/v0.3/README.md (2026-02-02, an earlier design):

Smaller footprint, same circuit as v0.2
Working but to optimize (cf. v0.4)

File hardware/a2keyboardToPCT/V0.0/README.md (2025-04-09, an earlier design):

PCB Kicad and Gerber files.  
FreeCad (a2keyboardToPCT-db25.FCStd) and STL (a2keyboardToPCT-db25.stl) for 3D Printing enclosure for Apple IIe db25 cutout.

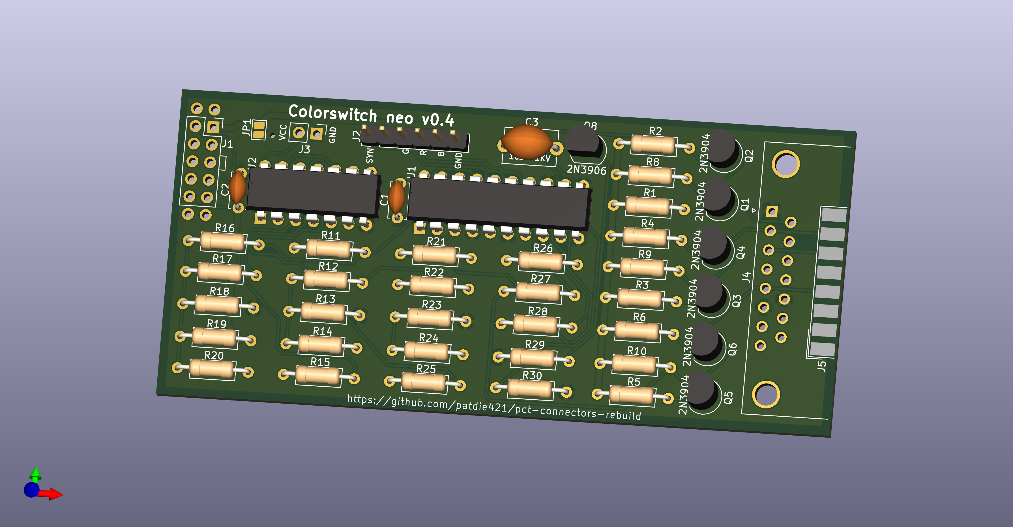
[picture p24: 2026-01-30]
hardware/colorswitch/v0.4/colorswitch.png

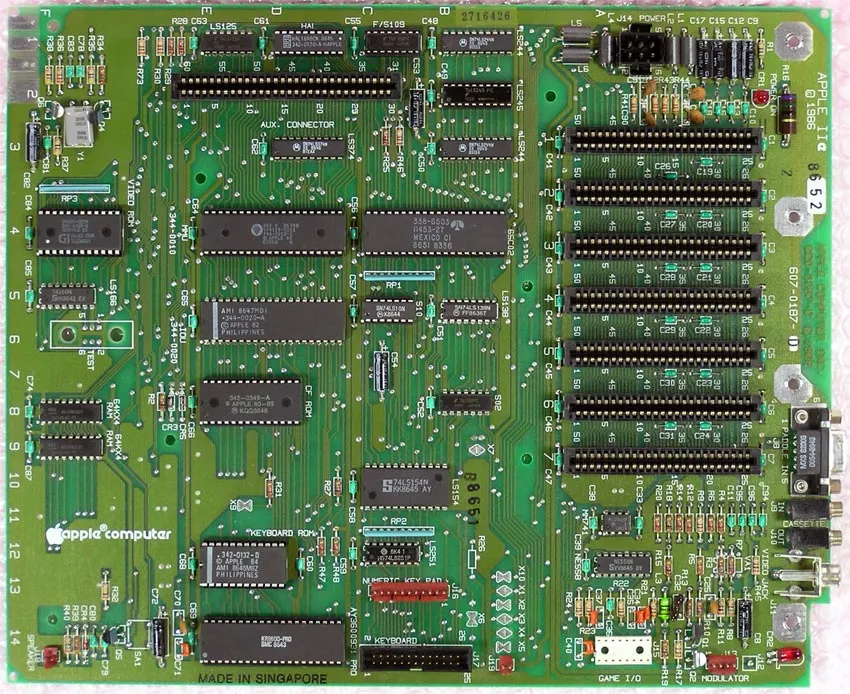
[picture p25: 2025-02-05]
images/2EUS.png

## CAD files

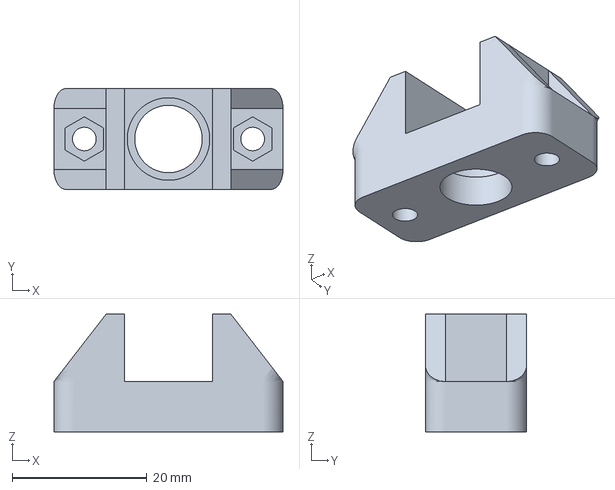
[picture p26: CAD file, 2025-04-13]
hardware/a2keyboardToPCT-XT2AT/a2keyboardToPCT-XT2AT-db9-Body.3mf
34.0 x 15.0 x 17.5 mm

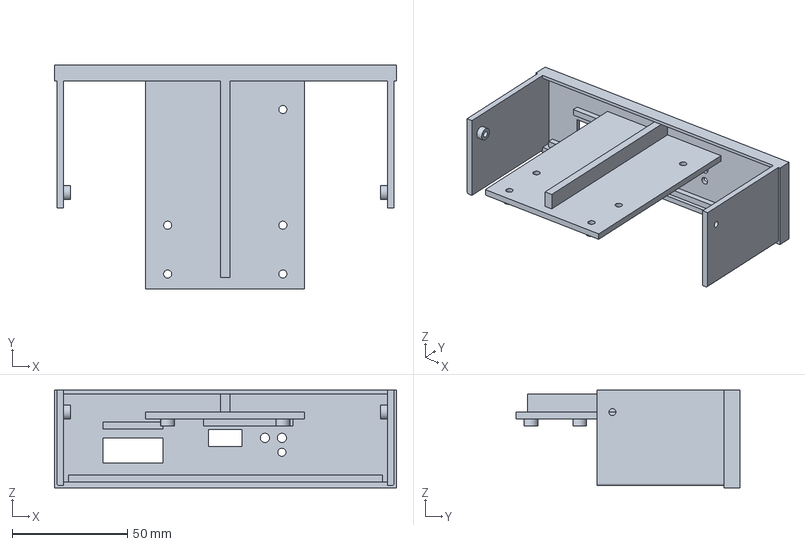
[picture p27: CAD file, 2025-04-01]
hardware/transdriveGotek/v0.0/525gotek-Body.3mf
148.1 x 97.0 x 42.3 mm

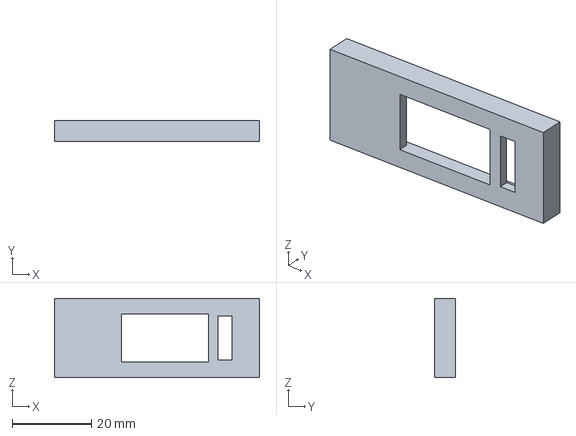
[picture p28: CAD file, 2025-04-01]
hardware/transdriveGotek/v0.0/525gotek-screen support.3mf
51.6 x 5.18 x 20.0 mm

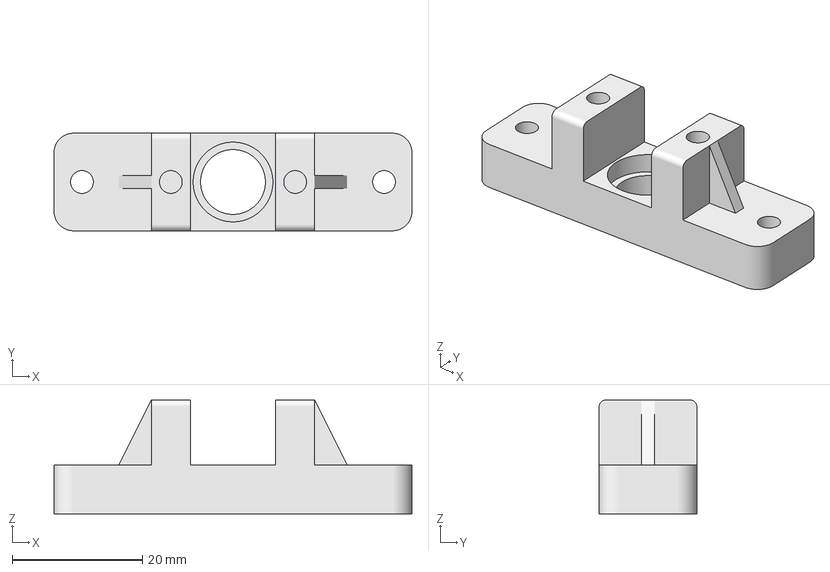
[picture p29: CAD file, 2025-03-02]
hardware/a2keyboardToPCT-XT2AT/a2keyboardToPCT-XT2AT-db25.FCStd
55.0 x 15.0 x 17.5 mm

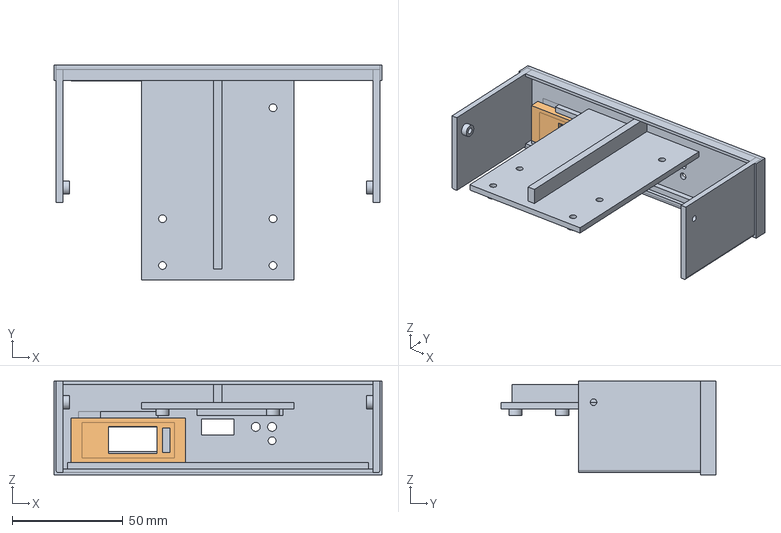
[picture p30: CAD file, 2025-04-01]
hardware/transdriveGotek/v0.0/525gotek.FCStd
148.1 x 97.0 x 42.3 mm
screen support

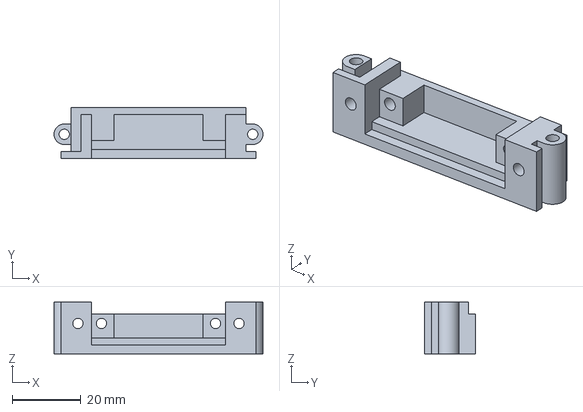
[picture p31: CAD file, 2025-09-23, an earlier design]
hardware/colorswitch/v0.2/braket/colorswitch-braket-Body.3mf
61.0 x 14.8 x 15.2 mm

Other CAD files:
hardware/a2keyboardToPCT-XT2AT/a2keyboardToPCT-XT2AT-db9.FCStd
hardware/colorswitch/v0.2/braket/colorswitch-braket.FCStd
hardware/a2keyboardToPCT-XT2AT/a2keyboardToPCT-XT2AT-db25.stl
hardware/colorswitch/v0.2/braket/colorswitch-braket-Body.stl

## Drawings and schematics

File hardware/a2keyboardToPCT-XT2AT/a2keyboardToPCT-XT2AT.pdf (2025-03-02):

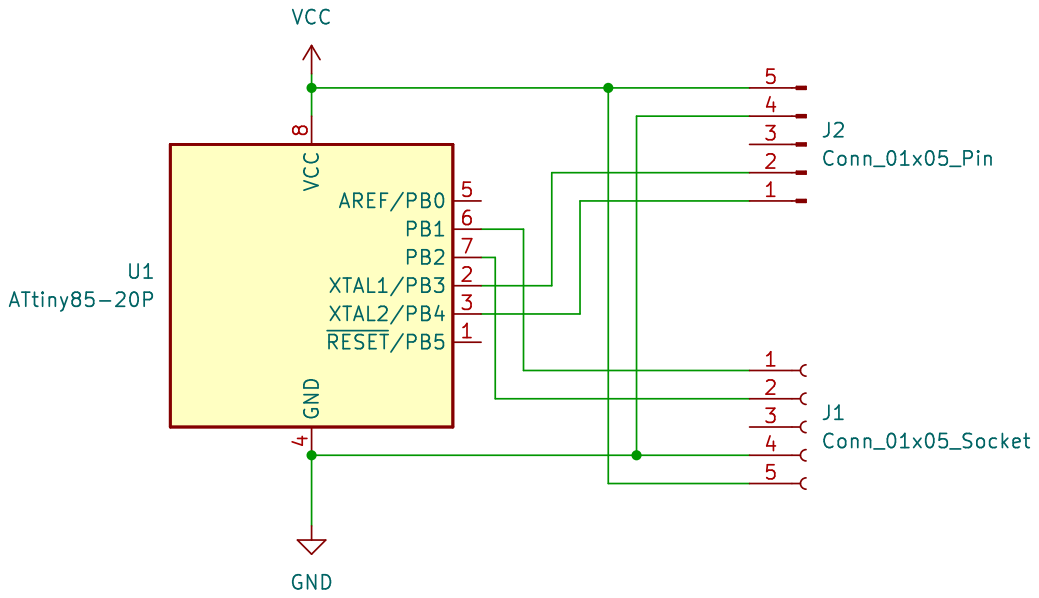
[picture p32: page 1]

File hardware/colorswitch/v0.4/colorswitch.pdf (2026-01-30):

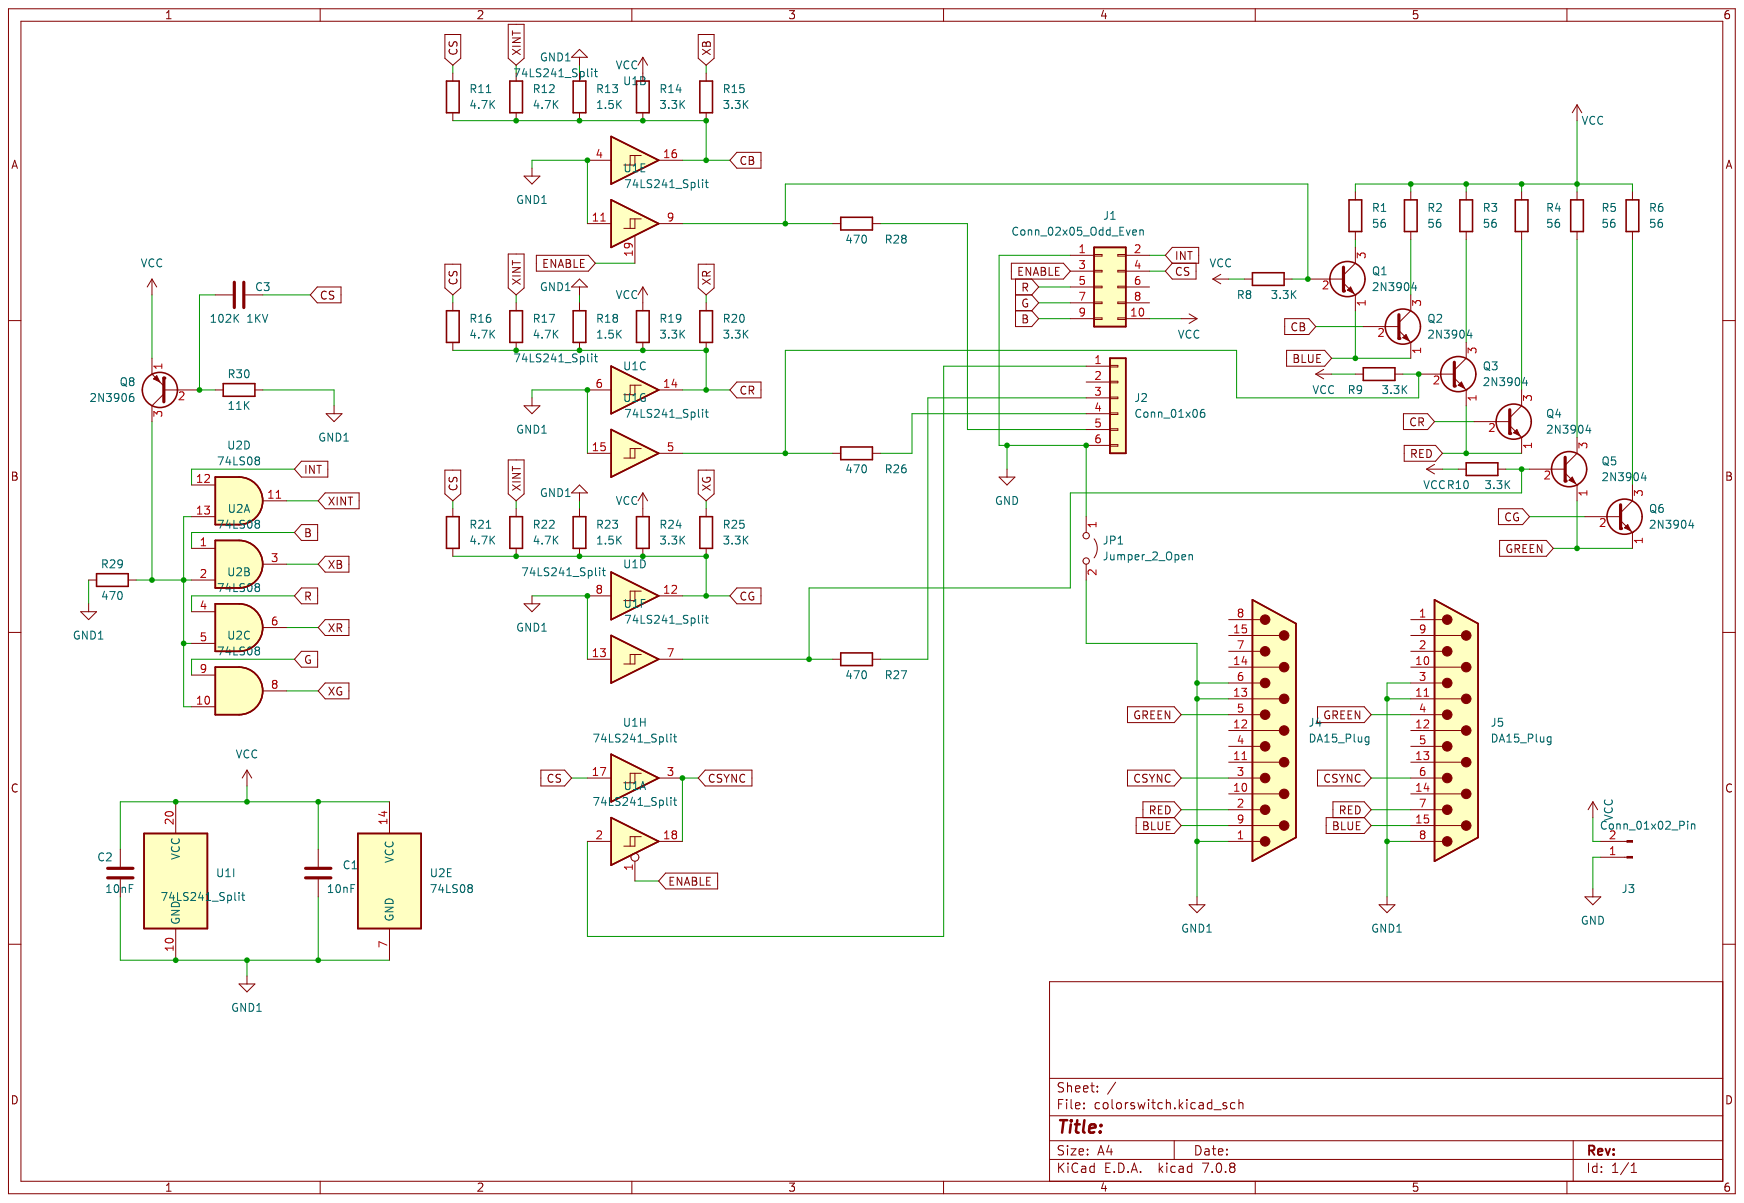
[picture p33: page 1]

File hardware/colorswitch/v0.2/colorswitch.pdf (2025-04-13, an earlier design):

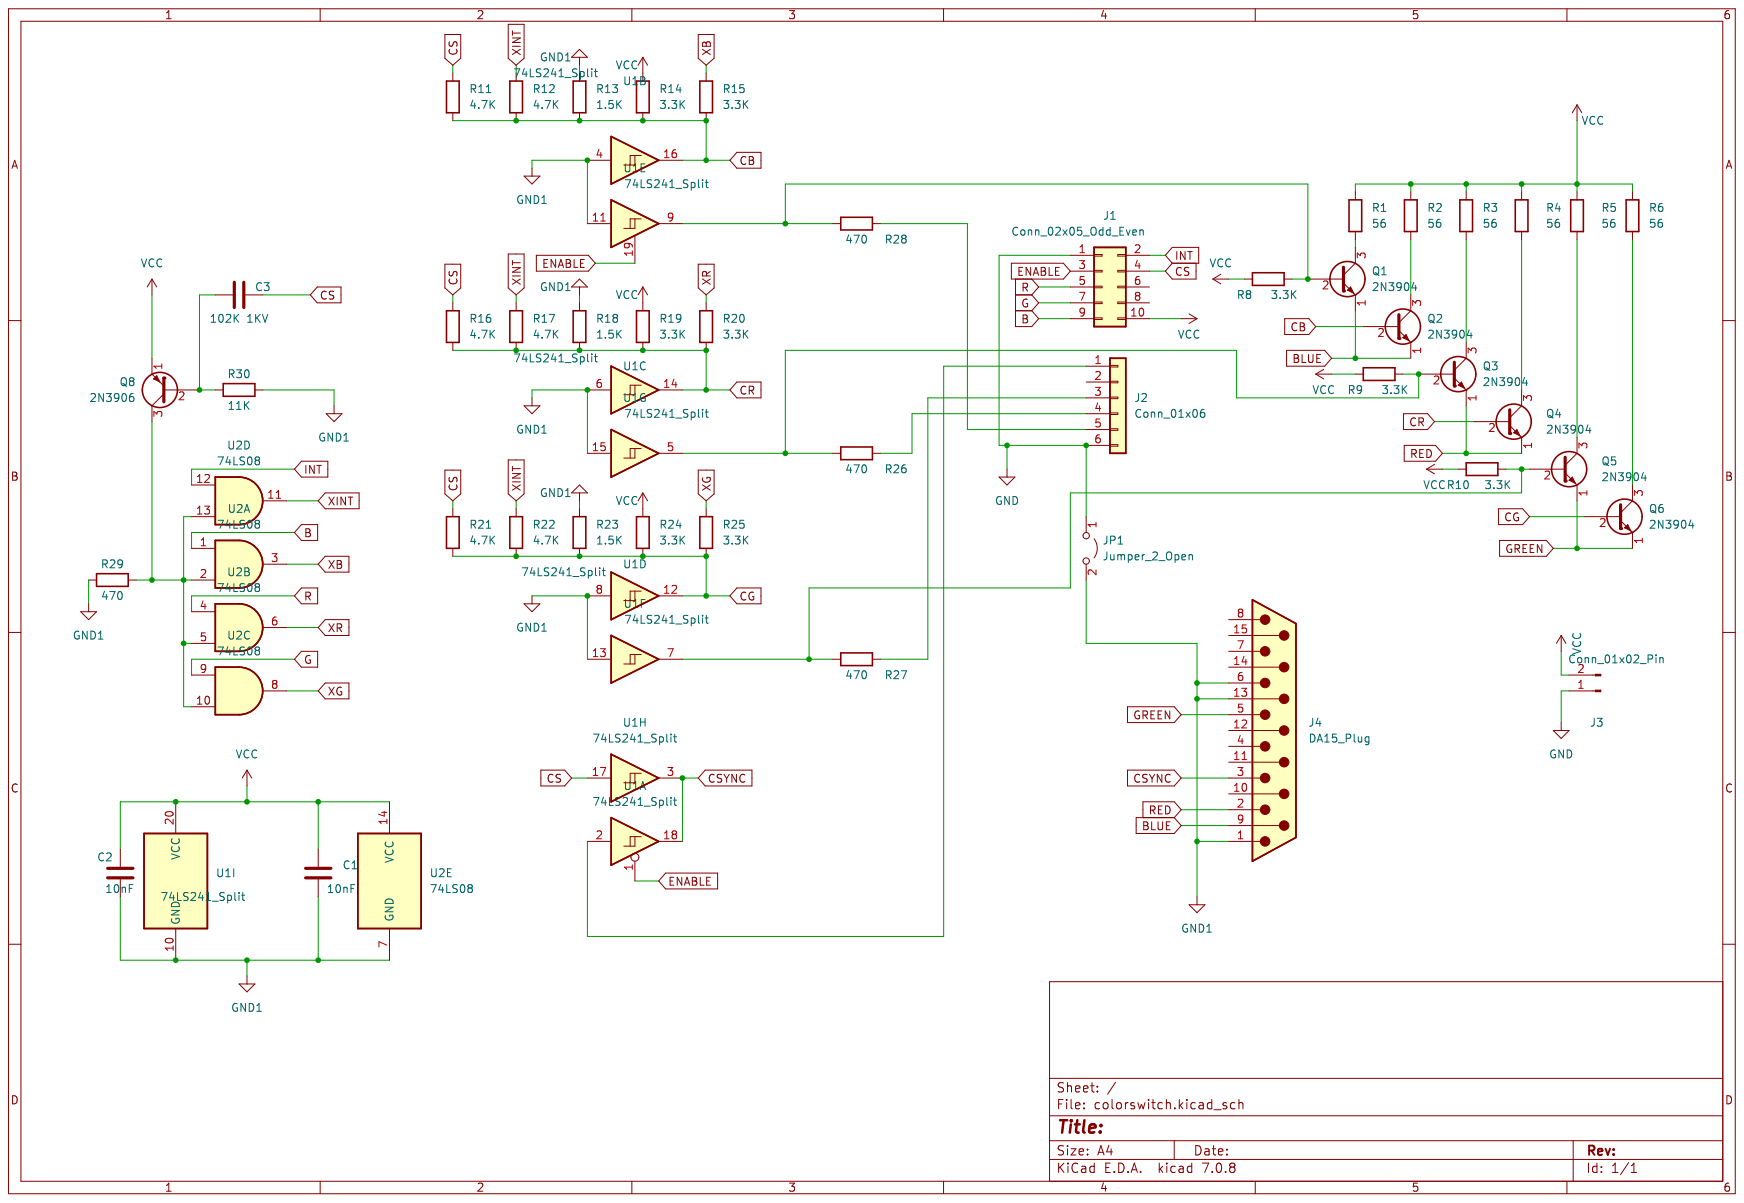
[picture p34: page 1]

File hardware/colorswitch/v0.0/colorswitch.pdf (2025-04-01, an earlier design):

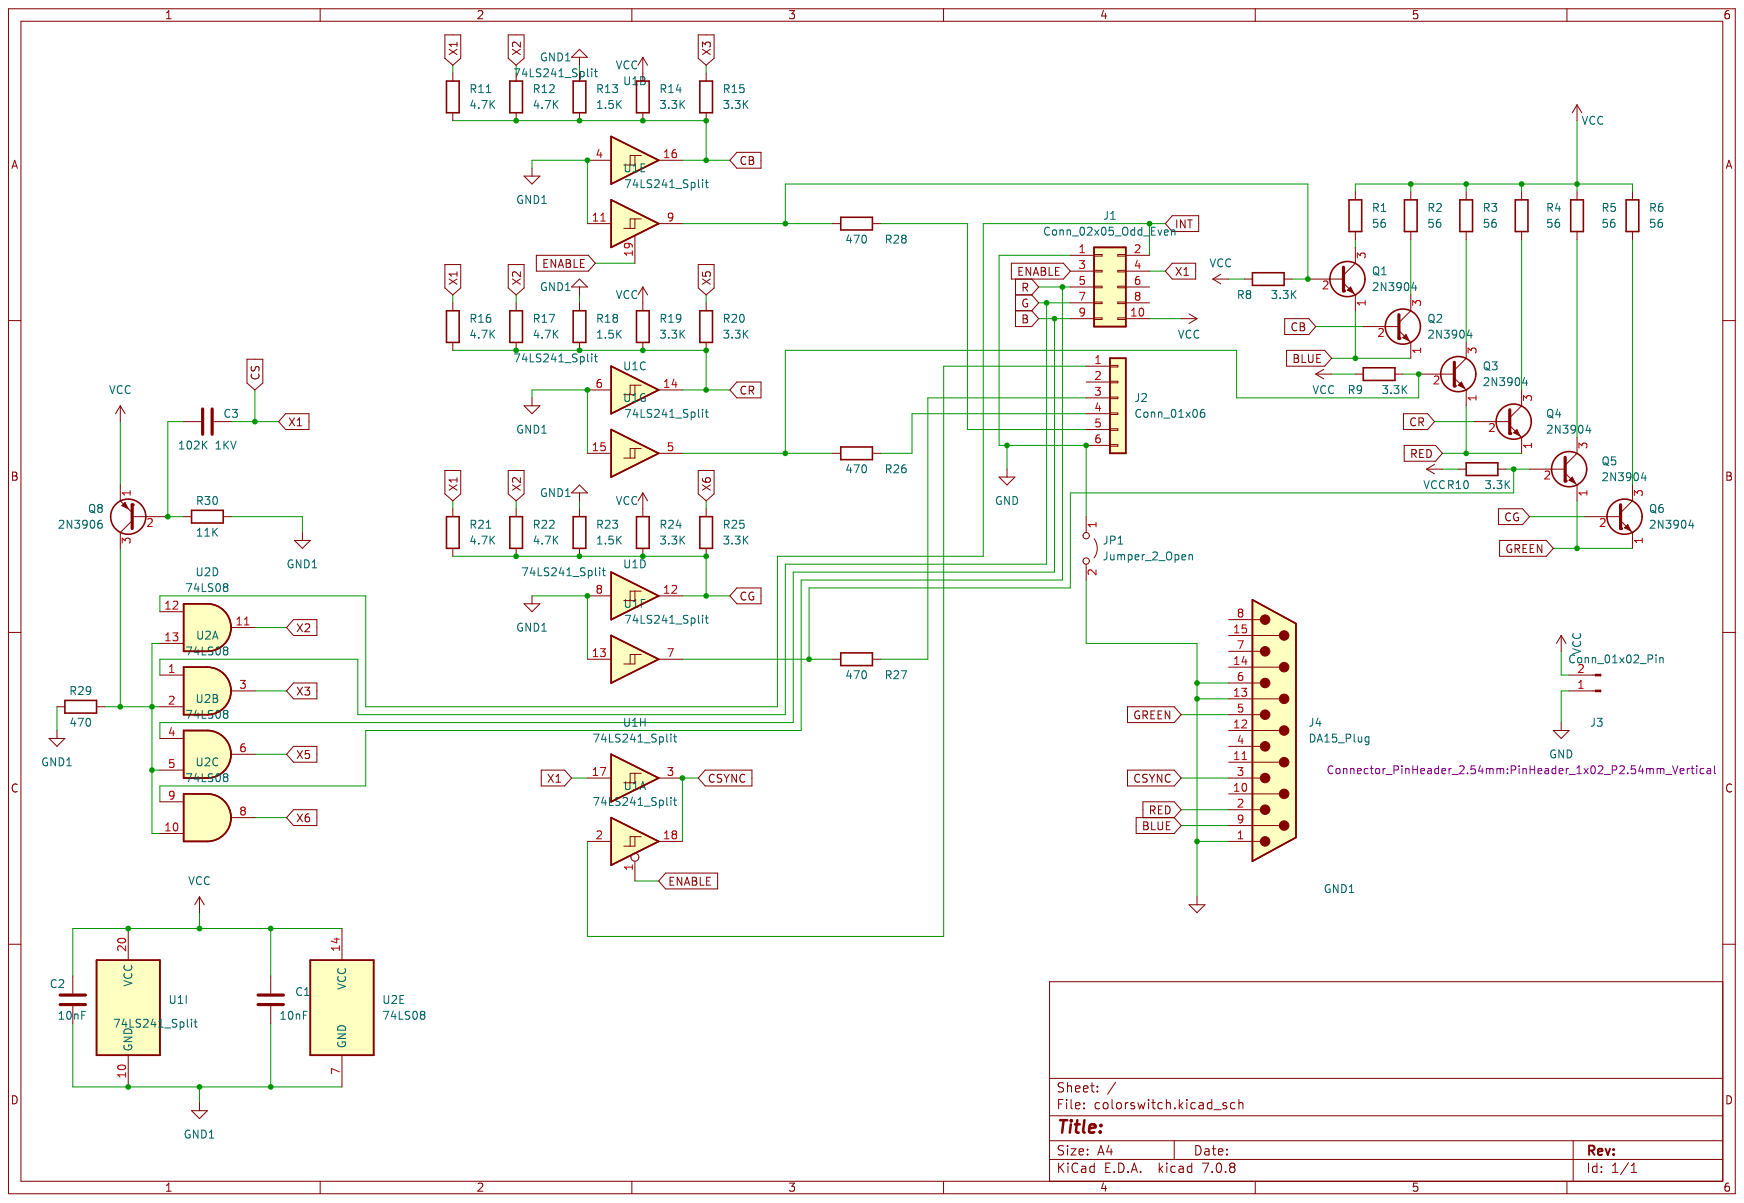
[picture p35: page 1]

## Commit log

2025-04-09 Rename hardware/525gotek-screen support.3mf to hardware/transdriveGotek /v0.0/525gotek-screen support.3mf
    [525gotek-screen support.3mf]
2025-04-09 Rename 525gotek-screen support.3mf to 525gotek-screen support.3mf
    [525gotek-screen support.3mf]
2025-12-30 new colorswitch
    [colorswitch.kicad_pcb, colorswitch.kicad_sch]
2025-12-30 add colorswitch v0.3 gerber files
2026-01-30 Update colorswitch.kicad_pcb to version 0.4
    [colorswitch.kicad_pcb]
2026-01-30 Update colorswitch.kicad_prl to version 0.4
2026-01-30 Update colorswitch.kicad_pro to version 0.4
2026-02-15 Fix typo in README for Sub-D connector description
    Corrected a typo in the README regarding the Sub-D connector.
